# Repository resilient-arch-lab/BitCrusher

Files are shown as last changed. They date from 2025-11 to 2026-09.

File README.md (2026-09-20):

# BitCrusher: An Affordable, Open Source, Electromagnetic Fault Injection Platform
_NOTE: This repository is still under construction, and may be difficult to navigate in its current state_

Security researchers need attainable, effective tooling to secure computing infrastructure against physical attacks. Tools for hardware security research have been
getting cheaper and more effective over recent years, but EMFI tooling has been left behind. The cost of commercial EMFI tooling is typically on the order of tens to hundreds of thousands of dollars, and the highly-coupled proprietary equipment offers little insight to researchers developing or characterizing EMFI techniques. BitCrusher is being developed with the goal of addressing several challenges in this space:

- Supporting the continued improvement of open EMFI platform design techniques by contributing to the thread of research on the design of EMFI equipment
- Supporting the improvement of practical EMFI techniques and countermeasures through attainable and open domain specific instrumentation
- Lowering the high barrier to entry of replicating and expanding upon existing EMFI research by providing high performance equipment that is both affordable and easy to integrate with common existing hardware security instrumentation frameworks (e.g. ChipWhisperer)

## State of BitCrusher
BitCrusher was started as an undergraduate senior project in September 2025. Beginning April 2026, development efforts have been focused on working out design flaws and thoroughly verifying device performance. 

## Licensing
Following the licensing guidelines of [OSHWA](https://oshwa.org/), the components of BitCrusher fall under a combination of OSI-approved licenses. The following licenses were selected with the goals of maximizing this work's benefit to the open hardware and open security research communities and ensuring potential commercial utilization of this work similarly benefits those communities.  

**Firmware and Software:** BitCrusher firmware and software fall under the [GNU Affero General Public License v3.0](https://www.gnu.org/licenses/agpl-3.0.html) (AGPL-3.0). This includes the BitCrusher device firmware (`/firmware`) and the host-side python interface (`/interface`).  

**Hardware design:** The design materials of BitCrusher (including but not limited to materials in `/design`, excluding those covered under the firmware / software licensing scheme) are licensed under the [CERN Open Hardware Licence Version 2 – Strongly Reciprocal](https://gitlab.com/ohwr/project/cernohl/-/wikis/uploads/819d71bea3458f71fba6cf4fb0f2de6b/cern_ohl_s_v2.txt) (CERN-OHL-S-2.0). 

**Documentation:** Current BitCrusher documentation, including but not limited to user guides / instructions, written documentation of the design, and written engineering work / documentation is under the [Creative Commons Attribution-ShareAlike 4.0 International](https://creativecommons.org/licenses/by-sa/4.0/) license (CC BY-SA 4.0). In cases where documentation is accompanied by code, such as simulations and calculations in `/design-resources`, the code falls under the AGPL-3.0 license while the written work falls under the CC BY-SA 4.0 license. 

While there is currently no sound structure for project governance, the policy for potential future contributions to the project's documentation is that the contributions should be CC BY-SA 4.0 licensed under the title "BitCrusher" and attributed to the respective contributor(s).  

**Branding:** Since this work was named after the [digital audio effect](https://en.wikipedia.org/wiki/Bitcrusher), as well as the fact that this project is a non-commercial endeavor, no restrictions apply to the use of the name BitCrusher.

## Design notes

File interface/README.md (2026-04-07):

# Installation
1. initialize submodules
2. install libftd2xx on OS (e.g. from AUR)
3. run `configure-ft230x.sh` with the device connected
4. build `src/stm32flash` with `make`

*TODO: Finish this*

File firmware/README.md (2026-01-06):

# BitChrusher Firmware
## High Voltage Generation Control

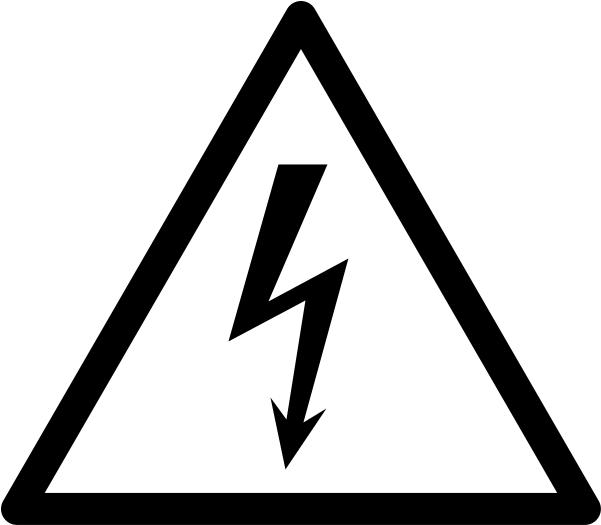
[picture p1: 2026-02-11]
design/graphics/high-voltage.jpg

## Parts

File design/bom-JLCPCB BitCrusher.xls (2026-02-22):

JLCPCB BOM Tool - BOM Matching
BOM name：bom-JLCPCB Assembly Order.xlsx |  |  | Download Time：2026-02-12 00:46:41 |  |  |  | * Our matching results are updated in real-time, but stock and prices may change. If it's been over 24 hours, please re-match before placing your order.
PCB Assembled Qty：5 |  |  | Est. Total Price：179.6794
Your BOM |  |  |  |  | Matched Parts |  |  |  |  |  |  | Order Information
Top Designator | Bottom Designator | Comment | Footprint | JLCPCB Part # | Matches | Part # | Manufacturer | Footprint | Description | Category | Warning | JLCPCB Part # | Product link | Lib Type | Qty | Source | Total Price ($)
C1,C11,C20,C21 |  | 4.7u | 0402 |  | Select by Customer | GRM155R61E475ME15D | Murata Electronics | 0402 | 25V 4.7uF X5R ±20% 0402 Multilayer Ceramic Capacitors MLCC - SMD/SMT ROHS | Multilayer Ceramic Capacitors MLCC - SMD/SMT | 1.The comment (GRM155R61E475ME15D) of this part does not match the one (4.7u) provided in your BOM. Please confirm; | C2858031 | https://jlcpcb.com/partdetail/3058877-GRM155R61E475ME15D/C2858031 | Extended | 24 | 24 JLCPCB | 0.9672
C6 |  | 10n | 0402 |  | Select by Customer | 0402B103K500NT | FH (Guangdong Fenghua Advanced Tech) | 0402 | 10nF 50V X7R ±10% 0402 Multilayer Ceramic Capacitors MLCC - SMD/SMT ROHS | Multilayer Ceramic Capacitors MLCC - SMD/SMT | 1.The comment (0402B103K500NT) of this part does not match the one (10n) provided in your BOM. Please confirm; | C1524 | https://jlcpcb.com/partdetail/1876-0402B103K500NT/C1524 | Extended | 20 | 20 JLCPCB | 0.022
C10,C12,C2,C3,C4,C5,C8,C9,CBOOT1,CBOOT2,CFF1,CFF2,COUT1,COUT5 |  | 100n | 0402 |  | Select by Customer | 0402B104K250NT | FH (Guangdong Fenghua Advanced Tech) | 0402 | 100nF 25V X7R ±10% 0402 Multilayer Ceramic Capacitors MLCC - SMD/SMT ROHS | Multilayer Ceramic Capacitors MLCC - SMD/SMT | 1.The comment (0402B104K250NT) of this part does not match the one (100n) provided in your BOM. Please confirm; 2.Multiple lines in the BOM have been matched to the same part. Please check if the matching is correct. ; 3.There may be multiple types of parts, but one type of part has been matched. Please check.; | C56392 | https://jlcpcb.com/partdetail/57421-0402B104K250NT/C56392 | Extended | 97 | 97 JLCPCB | 0.1358
C22,C23,C25 |  | 0.1u | 0402 |  | Select by Customer | 0402B104K250NT | FH (Guangdong Fenghua Advanced Tech) | 0402 | 100nF 25V X7R ±10% 0402 Multilayer Ceramic Capacitors MLCC - SMD/SMT ROHS | Multilayer Ceramic Capacitors MLCC - SMD/SMT | 1.The comment (0402B104K250NT) of this part does not match the one (0.1u) provided in your BOM. Please confirm; 2.Multiple lines in the BOM have been matched to the same part. Please check if the matching is correct. ; | C56392 | https://jlcpcb.com/partdetail/57421-0402B104K250NT/C56392 | Extended | 97 | 97 JLCPCB | 0.1358
C13,C14,C15,C16,C26,C7 |  | 1u | 0402 |  | Unconfirmed | CL05A105KA5NQNC | Samsung Electro-Mechanics | 0402 | 1uF 25V X5R ±10% 0402 Multilayer Ceramic Capacitors MLCC - SMD/SMT ROHS | Multilayer Ceramic Capacitors MLCC - SMD/SMT | 1.The comment (CL05A105KA5NQNC) of this part does not match the one (1u) provided in your BOM. Please confirm; | C52923 | https://jlcpcb.com/partdetail/53938-CL05A105KA5NQNC/C52923 | Basic | 40 | 40 JLCPCB | 0.132
C17,C18,CIN1,CIN2,CIN3,CIN4 |  | 4.7u | 1206 |  | Unconfirmed | 1206B475K500NT | FH (Guangdong Fenghua Advanced Tech) | 1206 | 4.7uF 50V X7R ±10% 1206 Multilayer Ceramic Capacitors MLCC - SMD/SMT ROHS | Multilayer Ceramic Capacitors MLCC - SMD/SMT | 1.The comment (1206B475K500NT) of this part does not match the one (4.7u) provided in your BOM. Please confirm; 2.There may be multiple types of parts, but one type of part has been matched. Please check.; | C29823 | https://jlcpcb.com/partdetail/30577-1206B475K500NT/C29823 | Basic | 38 | 38 JLCPCB | 1.4364
C19 |  | 240n | 0402 |  | Select by Customer | CL05B224KO5NNNC | Samsung Electro-Mechanics | 0402 | 16V 220nF X7R ±10% 0402 Multilayer Ceramic Capacitors MLCC - SMD/SMT ROHS | Multilayer Ceramic Capacitors MLCC - SMD/SMT |  | C16772 | https://jlcpcb.com/partdetail/17456-CL05B224KO5NNNC/C16772 | Basic | 20 | 20 JLCPCB | 0.082
C24,C27 |  | 1n | 0402 |  | Unconfirmed | 0402B102K500NT | FH (Guangdong Fenghua Advanced Tech) | 0402 | 1nF 50V X7R ±10% 0402 Multilayer Ceramic Capacitors MLCC - SMD/SMT ROHS | Multilayer Ceramic Capacitors MLCC - SMD/SMT | 1.The comment (0402B102K500NT) of this part does not match the one (1n) provided in your BOM. Please confirm; | C1523 | https://jlcpcb.com/partdetail/1875-0402B102K500NT/C1523 | Basic | 20 | 20 JLCPCB | 0.024
C28 |  | 68n | 0402 |  | Unconfirmed | CC0402KRX7R7BB683 | YAGEO | 0402 | 16V 68nF X7R ±10% 0402 Multilayer Ceramic Capacitors MLCC - SMD/SMT ROHS | Multilayer Ceramic Capacitors MLCC - SMD/SMT | 1.The comment (CC0402KRX7R7BB683) of this part does not match the one (68n) provided in your BOM. Please confirm; | C327019 | https://jlcpcb.com/partdetail/YAGEO-CC0402KRX7R7BB683/C327019 | Extended | 20 | 20 JLCPCB | 0.05
C29,C31 |  | 0.1n | 0402 |  | Unconfirmed | 0402CG101J500NT | FH (Guangdong Fenghua Advanced Tech) | 0402 | 100pF 50V C0G ±5% 0402 Multilayer Ceramic Capacitors MLCC - SMD/SMT ROHS | Multilayer Ceramic Capacitors MLCC - SMD/SMT | 1.The comment (0402CG101J500NT) of this part does not match the one (0.1n) provided in your BOM. Please confirm; 2.Multiple lines in the BOM have been matched to the same part. Please check if the matching is correct. ; | C1546 | https://jlcpcb.com/partdetail/1898-0402CG101J500NT/C1546 | Basic | 25 | 25 JLCPCB | 0.0275
C_CSF1 |  | 100p | 0402 |  | Unconfirmed | 0402CG101J500NT | FH (Guangdong Fenghua Advanced Tech) | 0402 | 100pF 50V C0G ±5% 0402 Multilayer Ceramic Capacitors MLCC - SMD/SMT ROHS | Multilayer Ceramic Capacitors MLCC - SMD/SMT | 1.The comment (0402CG101J500NT) of this part does not match the one (100p) provided in your BOM. Please confirm; 2.Multiple lines in the BOM have been matched to the same part. Please check if the matching is correct. ; | C1546 | https://jlcpcb.com/partdetail/1898-0402CG101J500NT/C1546 | Basic | 25 | 25 JLCPCB | 0.0275
C30 |  | 22u | 0603 |  | Unconfirmed
C32,C33,C34 |  | 10p | 0402 |  | Unconfirmed | CL05C100JB5NNNC | Samsung Electro-Mechanics | 0402 | 10pF 50V C0G ±5% 0402 Multilayer Ceramic Capacitors MLCC - SMD/SMT ROHS | Multilayer Ceramic Capacitors MLCC - SMD/SMT | 1.The comment (CL05C100JB5NNNC) of this part does not match the one (10p) provided in your BOM. Please confirm; | C32949 | https://jlcpcb.com/partdetail/33914-CL05C100JB5NNNC/C32949 | Basic | 25 | 25 JLCPCB | 0.1125
CBANK1,CBANK2,CBANK3,CBANK4,CBANK5 |  | FS55X105K631EHG | 2220 |  | Select by System | FS55X105K631EHG | PSA(Prosperity Dielectrics) | 2220 | 1uF 630V X7R ±10% 2220 Multilayer Ceramic Capacitors MLCC - SMD/SMT ROHS | Multilayer Ceramic Capacitors MLCC - SMD/SMT |  | C784102 | https://jlcpcb.com/partdetail/839502-FS55X105K631EHG/C784102 | Extended | 25 | 25 JLCPCB | 10.265
CHF1,CHF2 |  | 220n | 0805 |  | Unconfirmed | CL21B224KBFNNNE | Samsung Electro-Mechanics | 0805 | 220nF 50V X7R ±10% 0805 Multilayer Ceramic Capacitors MLCC - SMD/SMT ROHS | Multilayer Ceramic Capacitors MLCC - SMD/SMT | 1.The comment (CL21B224KBFNNNE) of this part does not match the one (220n) provided in your BOM. Please confirm; | C5378 | https://jlcpcb.com/partdetail/5810-CL21B224KBFNNNE/C5378 | Basic | 20 | 20 JLCPCB | 0.232
COUT2,COUT3,COUT4,COUT6,COUT7,COUT8 |  | 22u | 1210 |  | Select by Customer | GRM32ER71E226KE15L | Murata Electronics | 1210 | 22uF 25V X7R ±10% 1210 Multilayer Ceramic Capacitors MLCC - SMD/SMT ROHS | Multilayer Ceramic Capacitors MLCC - SMD/SMT | 1.The comment (GRM32ER71E226KE15L) of this part does not match the one (22u) provided in your BOM. Please confirm; | C21397 | https://jlcpcb.com/partdetail/MurataElectronics-GRM32ER71E226KE15L/C21397 | Extended | 30 | 30 JLCPCB | 6.807
D1,D2 |  | SP3031-01ETG | D_SOD-882 |  | Select by System | SP3031-01ETG | Littelfuse | SOD-882 | 0.8pF 1 1uA 5A@8/20us 5V 6V 7.5V IEC 61000-4-2、IEC 61000-4-5、IEC 61000-4-4 TVS Unidirectional SOD-882 ESD and Surge Protection (TVS/ESD) ROHS | ESD And Surge Protection (TVS/ESD) |  | C207283 | https://jlcpcb.com/partdetail/Littelfuse-SP303101ETG/C207283 | Extended | 12 | 12 JLCPCB | 1.9272
D3,D6 |  | 1N5822 | D_DO-201AD_P12.70mm_Horizontal |  | Select by System | 1N5822 | MDD(Microdiode Semiconductor) | DO-201AD | -65℃~+125℃ 1 Independent 3A 40V 500uA@40V 525mV@3A 80A DO-201AD Schottky Diodes ROHS | Schottky Diodes |  | C2476 | https://jlcpcb.com/partdetail/MDD_Microdiode_Semiconductor-1N5822/C2476 | Extended | 11 | 11 JLCPCB | 1.2331
D4 |  | D | D_SMA |  | Select by Customer | US2M | MDD(Microdiode Semiconductor) | SMA | -55℃~+150℃ 1.7V@2A 1kV 2A 50A 5uA@1kV 75ns Independent SMA Fast Recovery / High Efficiency Diodes ROHS | Fast Recovery / High Efficiency Diodes |  | C64958 | https://jlcpcb.com/partdetail/MDD_Microdiode_Semiconductor-US2M/C64958 | Extended | 13 | 13 JLCPCB | 0.286
D5 |  | 1N5819 | D_SOD-323 |  | Unconfirmed | 1N5819WS | Guangdong Hottech | SOD-323 | 1 Independent 1A 25A 40V 500uA@40V 600mV@1A SOD-323 Schottky Diodes ROHS | Schottky Diodes | 1.The comment (1N5819WS) of this part does not match the one (1N5819) provided in your BOM. Please confirm; | C191023 | https://jlcpcb.com/partdetail/GuangdongHottech-1N5819WS/C191023 | Basic | 20 | 20 JLCPCB | 0.174
D7 |  | D_Schottky | D_SOD-123 |  | Select by Customer | B5819W SL | Jiangsu Changjing Electronics Technology Co., Ltd. | SOD-123 | 1A 40V 600mV@1A 9A Independent SOD-123 Schottky Diodes ROHS | Schottky Diodes |  | C8598 | https://jlcpcb.com/partdetail/9093-B5819WSL/C8598 | Basic | 20 | 20 JLCPCB | 0.48
D8,D9 |  | HF1600G | D_DO-41_SOD81_P7.62mm_Horizontal |  | Select by System | HF1600G | LRC | DO-41 | -50℃~+150℃@(Tj) 1.2kV 1A 3.4V@0.5A 5uA@1200V 75ns Independent DO-41 Switching Diodes ROHS | Switching Diodes |  | C411154 | https://jlcpcb.com/partdetail/LRC-HF1600G/C411154 | Extended | 12 | 12 JLCPCB | 1.3932
J1 |  | BNC | KHBNC503511 |  | Select by Customer | KH-BNC50-3511 | Shenzhen Kinghelm Elec | 插件 | -55℃~+155℃ 1 3GHz 50Ω 9.5mm BNC Board Side Elbow Inner Bore Plugin Coaxial Connectors (RF) ROHS | Coaxial Connectors (RF) |  | C2837587 | https://jlcpcb.com/partdetail/Shenzhen_KinghelmElec-KH_BNC503511/C2837587 | Extended | 5 | 5 JLCPCB | 4.05
J2 |  | BWSMA-KWE-Z001 | SMA_BAT_Wireless_BWSMA-KWE-Z001 |  | Select by System | BWSMA-KWE-Z001 | BAT WIRELESS | 插件 | 1 5.3mm 50Ω Board Side Elbow Inner Bore SMA Plugin Coaxial Connectors (RF) ROHS | Coaxial Connectors (RF) |  | C496551 | https://jlcpcb.com/partdetail/BATWIRELESS-BWSMA_KWEZ001/C496551 | Extended | 5 | 5 JLCPCB | 2.479
J3,J4 |  | BWSMA-KE-Z001 | SMA_BAT_Wireless_BWSMA-KE-Z001 |  | Select by System | BWSMA-KE-Z001 | BAT WIRELESS | 插件 | -65℃~+165℃ 1 50Ω Board Side Inner Bore Positive Pin SMA Plugin Coaxial Connectors (RF) ROHS | Coaxial Connectors (RF) |  | C496549 | https://jlcpcb.com/partdetail/BATWIRELESS-BWSMA_KEZ001/C496549 | Extended | 10 | 10 JLCPCB | 3.127
J5 |  | SHOUHANTYPE-C14PCC-2.6 | TYPE-C-TH_TYPE-C-14P-CC-2.6 |  | Select by System | TYPE-C 14P CC-2.6 | SHOU HAN | 插件 | -30℃~+85℃ 1 10,000 Cycles 14P 20V 3A Black Female Type-C Vertical, Flag 插件 USB Connectors ROHS | USB Connectors |  | C5187475 | https://jlcpcb.com/partdetail/SHOUHAN-TYPE_C_14P_CC_26/C5187475 | Extended | 5 | 5 JLCPCB | 2.9845
J6,J7 |  | Conn_01x04_Pin | PinHeader_1x04_P2.54mm_Vertical |  | Select by Customer | 2.54-1*40P直针 | BOOMELE(Boom Precision Elec) | 插件,P=2.54mm | -25℃~+85℃ 1 1x40P 2.54mm 2.5mm 3A 3mm 40P 6mm Black Brass Gold Pin Header Through Hole Plugin,P=2.54mm Pin Headers ROHS | Pin Headers | 1.Multiple lines in the BOM have been matched to the same part. Please check if the matching is correct. ; | C2337 | https://jlcpcb.com/partdetail/2712-2_54_1_40P/C2337 | Extended | 20 | 20 JLCPCB | 2.73
J8,J9 |  | Conn_01x03_Pin | PinHeader_1x03_P2.54mm_Vertical |  | Select by Customer | 2.54-1*40P直针 | BOOMELE(Boom Precision Elec) | 插件,P=2.54mm | -25℃~+85℃ 1 1x40P 2.54mm 2.5mm 3A 3mm 40P 6mm Black Brass Gold Pin Header Through Hole Plugin,P=2.54mm Pin Headers ROHS | Pin Headers | 1.Multiple lines in the BOM have been matched to the same part. Please check if the matching is correct. ; | C2337 | https://jlcpcb.com/partdetail/2712-2_54_1_40P/C2337 | Extended | 20 | 20 JLCPCB | 2.73
L1 |  | 15.4u | L_TechFuse_SL0630 |  | Select by Customer | SL0630-150M | TECHFUSE | SMD,7.1x6.6mm | 115mΩ 15uH 3.5A 4.5A ±20% SMD,7.1x6.6mm Inductors (SMD) ROHS | Inductors (SMD) |  | C22463824 | https://jlcpcb.com/partdetail/TECHFUSE-SL0630150M/C22463824 | Extended | 5 | 5 JLCPCB | 0.424
L2 |  | 12.1u | L_TechFuse_SL0630 |  | Select by Customer | SL0630-100M | TECHFUSE | SMD,7.1x6.6mm | 10uH 5.5A 5A 99.5mΩ ±20% SMD,7.1x6.6mm Inductors (SMD) ROHS | Inductors (SMD) |  | C22463823 | https://jlcpcb.com/partdetail/TECHFUSE-SL0630100M/C22463823 | Extended | 5 | 5 JLCPCB | 0.394
Q1 |  | Q_NMOS_DGS | TO-252-2 |  | Select by Customer | SW4N60 | Samwin | TO-252-2 | -55℃~+150℃ 1 N-channel 147W 17nC 2.2Ω@10V 4.5V 4A 586pF 600V 7.6pF 71pF N-Channel TO-252-2 MOSFETs ROHS | MOSFETs |  | C381523 | https://jlcpcb.com/partdetail/Samwin-SW4N60/C381523 | Extended | 5 | 5 JLCPCB | 1.26
Q2 |  | 2SA1213 | SOT-89-3 |  | Select by System | 2SA1213 | hongjiacheng | SOT-89 | -55℃~+150℃ 1 PNP 100nA 120MHz 2A 500mV 500mW 50V 5V 70 PNP SOT-89 Bipolar (BJT) ROHS | Bipolar (BJT) |  | C20069144 | https://jlcpcb.com/partdetail/hongjiacheng-2SA1213/C20069144 | Extended | 7 | 7 JLCPCB | 0.4424
R1,R5 |  | 10k | 0402 |  | Unconfirmed | 0402WGF1002TCE | UNI-ROYAL(Uniroyal Elec) | 0402 | -55℃~+155℃ 10kΩ 50V 62.5mW Thick Film Resistor ±1% ±100ppm/℃ 0402 Chip Resistor - Surface Mount ROHS | Chip Resistor - Surface Mount | 1.The comment (0402WGF1002TCE) of this part does not match the one (10k) provided in your BOM. Please confirm; | C25744 | https://jlcpcb.com/partdetail/26487-0402WGF1002TCE/C25744 | Basic | 20 | 20 JLCPCB | 0.016
R2,R3 |  | 5.1k | 0603 |  | Unconfirmed | 0603WAF5101T5E | UNI-ROYAL(Uniroyal Elec) | 0603 | -55℃~+155℃ 100mW 5.1kΩ 75V Thick Film Resistor ±1% ±100ppm/℃ 0603 Chip Resistor - Surface Mount ROHS | Chip Resistor - Surface Mount | 1.The comment (0603WAF5101T5E) of this part does not match the one (5.1k) provided in your BOM. Please confirm; | C23186 | https://jlcpcb.com/partdetail/23913-0603WAF5101T5E/C23186 | Basic | 20 | 20 JLCPCB | 0.024
R4 |  | 4.7k | 0402 |  | Unconfirmed | 0402WGF4701TCE | UNI-ROYAL(Uniroyal Elec) | 0402 | -55℃~+155℃ 4.7kΩ 50V 62.5mW Thick Film Resistor ±1% ±100ppm/℃ 0402 Chip Resistor - Surface Mount ROHS | Chip Resistor - Surface Mount | 1.The comment (0402WGF4701TCE) of this part does not match the one (4.7k) provided in your BOM. Please confirm; | C25900 | https://jlcpcb.com/partdetail/26643-0402WGF4701TCE/C25900 | Basic | 20 | 20 JLCPCB | 0.016
R6 |  | 60k | 0603 |  | Select by Customer | 0603WAF6042T5E | UNI-ROYAL(Uniroyal Elec) | 0603 | -55℃~+155℃ 100mW 60.4kΩ 75V Thick Film Resistor ±1% ±100ppm/℃ 0603 Chip Resistor - Surface Mount ROHS | Chip Resistor - Surface Mount | 1.The comment (0603WAF6042T5E) of this part does not match the one (60k) provided in your BOM. Please confirm; | C23089 | https://jlcpcb.com/partdetail/23816-0603WAF6042T5E/C23089 | Extended | 20 | 20 JLCPCB | 0.024
R7 |  | 1.6 | 0603 |  | Unconfirmed | FRC0603F1R60TS | FOJAN | 0603 | -55℃~+155℃ 1.6Ω 100mW 75V Thick Film Resistor ±1% ±200ppm/℃ 0603 Chip Resistor - Surface Mount ROHS | Chip Resistor - Surface Mount | 1.The comment (FRC0603F1R60TS) of this part does not match the one (1.6) provided in your BOM. Please confirm; | C2930144 | https://jlcpcb.com/partdetail/FOJAN-FRC0603F1R60TS/C2930144 | Extended | 20 | 20 JLCPCB | 0.028
R10,R11,R12,R8,R9 |  | 2M | 0805 |  | Select by Customer | 0805W8F2004T5E | UNI-ROYAL(Uniroyal Elec) | 0805 | -55℃~+155℃ 125mW 150V 2MΩ Thick Film Resistor ±1% ±100ppm/℃ 0805 Chip Resistor - Surface Mount ROHS | Chip Resistor - Surface Mount | 1.The comment (0805W8F2004T5E) of this part does not match the one (2M) provided in your BOM. Please confirm; | C26112 | https://jlcpcb.com/partdetail/26855-0805W8F2004T5E/C26112 | Extended | 35 | 35 JLCPCB | 0.098
R13 |  | 1.5M,1000V,500mW |  |  | Unconfirmed
R14,R15,R16 |  | 1 | 0603 |  | Unconfirmed | 0603WAF100KT5E | UNI-ROYAL(Uniroyal Elec) | 0603 | -55℃~+155℃ 100mW 1Ω 75V Thick Film Resistor ±1% ±400ppm/℃ 0603 Chip Resistor - Surface Mount ROHS | Chip Resistor - Surface Mount | 1.The comment (0603WAF100KT5E) of this part does not match the one (1) provided in your BOM. Please confirm; | C22936 | https://jlcpcb.com/partdetail/23663-0603WAF100KT5E/C22936 | Basic | 25 | 25 JLCPCB | 0.05
R17 |  | 330 | 0603 |  | Unconfirmed | 0603WAF3300T5E | UNI-ROYAL(Uniroyal Elec) | 0603 | -55℃~+155℃ 100mW 330Ω 75V Thick Film Resistor ±1% ±100ppm/℃ 0603 Chip Resistor - Surface Mount ROHS | Chip Resistor - Surface Mount | 1.The comment (0603WAF3300T5E) of this part does not match the one (330) provided in your BOM. Please confirm; | C23138 | https://jlcpcb.com/partdetail/23865-0603WAF3300T5E/C23138 | Basic | 20 | 20 JLCPCB | 0.024
R18 |  | 10M | 0603 |  | Unconfirmed | 0603WAF1005T5E | UNI-ROYAL(Uniroyal Elec) | 0603 | -55℃~+155℃ 100mW 10MΩ 75V Thick Film Resistor ±1% ±100ppm/℃ 0603 Chip Resistor - Surface Mount ROHS | Chip Resistor - Surface Mount | 1.The comment (0603WAF1005T5E) of this part does not match the one (10M) provided in your BOM. Please confirm; | C7250 | https://jlcpcb.com/partdetail/7726-0603WAF1005T5E/C7250 | Basic | 20 | 20 JLCPCB | 0.036
R19,R23 |  | 4.3M | 0603 |  | Unconfirmed | FRC0603F4304TS | FOJAN | 0603 | -55℃~+155℃ 100mW 4.3MΩ 75V Thick Film Resistor ±1% ±100ppm/℃ 0603 Chip Resistor - Surface Mount ROHS | Chip Resistor - Surface Mount | 1.The comment (FRC0603F4304TS) of this part does not match the one (4.3M) provided in your BOM. Please confirm; | C2930152 | https://jlcpcb.com/partdetail/FOJAN-FRC0603F4304TS/C2930152 | Extended | 20 | 20 JLCPCB | 0.022
R20,R24 |  | 4.7M | 0603 |  | Unconfirmed | 0603WAF4704T5E | UNI-ROYAL(Uniroyal Elec) | 0603 | -55℃~+155℃ 100mW 4.7MΩ 75V Thick Film Resistor ±1% ±100ppm/℃ 0603 Chip Resistor - Surface Mount ROHS | Chip Resistor - Surface Mount | 1.The comment (0603WAF4704T5E) of this part does not match the one (4.7M) provided in your BOM. Please confirm; | C23163 | https://jlcpcb.com/partdetail/23890-0603WAF4704T5E/C23163 | Extended | 20 | 20 JLCPCB | 0.026
R21,R22 |  | 0R,200V,30A | 2512 |  | Select by Customer | 25121WJ0000T4E | UNI-ROYAL(Uniroyal Elec) | 2512 | -55℃~+155℃ 0Ω 1W 200V Thick Film Resistor ±5% ±800ppm/℃ 2512 Chip Resistor - Surface Mount ROHS | Chip Resistor - Surface Mount |  | C25469 | https://jlcpcb.com/partdetail/26212-25121WJ0000T4E/C25469 | Extended | 18 | 18 JLCPCB | 0.3906
R25 |  | 330 | 2512 |  | Unconfirmed | 3521330RFT | TE Connectivity | 2512 | -55℃~+155℃ 2W 330Ω Thick Film Resistor ±1% ±100ppm/℃ 2512 Chip Resistor - Surface Mount ROHS | Chip Resistor - Surface Mount | 1.The comment (3521330RFT) of this part does not match the one (330) provided in your BOM. Please confirm; | C4134246 | https://jlcpcb.com/partdetail/TEConnectivity-3521330RFT/C4134246 | Extended | 5 | 5 JLCPCB | 1.5555
R26 |  | 0 | 0603 |  | Unconfirmed | 0603WAF0000T5E | UNI-ROYAL(Uniroyal Elec) | 0603 | -55℃~+155℃ 0Ω 100mW 75V Thick Film Resistor ±1% 0603 Chip Resistor - Surface Mount ROHS | Chip Resistor - Surface Mount | 1.The comment (0603WAF0000T5E) of this part does not match the one (0) provided in your BOM. Please confirm; | C21189 | https://jlcpcb.com/partdetail/21903-0603WAF0000T5E/C21189 | Basic | 20 | 20 JLCPCB | 0.024
RCS1 |  | 500m,3W | 2512 |  | Select by Customer | HoJLR2512-3W-500mR-1% | Milliohm | 2512 | 3W 500mΩ Current Sense Resistor SMD ±1% 2512 Current Sense Resistors / Shunt Resistors ROHS | Current Sense Resistors / Shunt Resistors |  | C2904268 | https://jlcpcb.com/partdetail/Milliohm-HoJLR2512_3W_500mR_1/C2904268 | Extended | 7 | 7 JLCPCB | 0.4921
RFBB1 |  | 4.76K | 0603 |  | Select by Customer | 0603WAF4871T5E | UNI-ROYAL(Uniroyal Elec) | 0603 | -55℃~+155℃ 100mW 4.87kΩ 75V Thick Film Resistor ±1% ±100ppm/℃ 0603 Chip Resistor - Surface Mount ROHS | Chip Resistor - Surface Mount |  | C23045 | https://jlcpcb.com/partdetail/23772-0603WAF4871T5E/C23045 | Extended | 20 | 20 JLCPCB | 0.026
RFBB2 |  | 20k | 0603 |  | Select by System | 0603WAF2002T5E | UNI-ROYAL(Uniroyal Elec) | 0603 | -55℃~+155℃ 100mW 20kΩ 75V Thick Film Resistor ±1% ±100ppm/℃ 0603 Chip Resistor - Surface Mount ROHS | Chip Resistor - Surface Mount |  | C4184 | https://jlcpcb.com/partdetail/4591-0603WAF2002T5E/C4184 | Basic | 20 | 20 JLCPCB | 0.024
RFBT1,RFBT2,RPG1,RPG2 |  | 100k | 0603 |  | Unconfirmed | 0603WAF1003T5E | UNI-ROYAL(Uniroyal Elec) | 0603 | -55℃~+155℃ 100kΩ 100mW 75V Thick Film Resistor ±1% ±100ppm/℃ 0603 Chip Resistor - Surface Mount ROHS | Chip Resistor - Surface Mount | 1.There may be multiple types of parts, but one type of part has been matched. Please check.; | C25803 | https://jlcpcb.com/partdetail/26546-0603WAF1003T5E/C25803 | Basic | 30 | 30 JLCPCB | 0.033
RP_B1 |  | WSHP2818R0200FEA | WSHP2818R0200FEA |  | Select by System | WSHP2818R0200FEA | Vishay Intertech | 2818 | 10W 20mΩ Current Sense Resistor SMD ±1% ±75ppm/℃ 2818 Current Sense Resistors / Shunt Resistors ROHS | Current Sense Resistors / Shunt Resistors |  | C2090752 | https://jlcpcb.com/partdetail/VishayIntertech-WSHP2818R0200FEA/C2090752 | Extended | 5 | 5 JLCPCB | 5.771
R_ADJ1 |  | 20k | 0402 |  | Select by Customer | 0402WGJ0203TCE | UNI-ROYAL(Uniroyal Elec) | 0402 | -55℃~+155℃ 20kΩ 50V 62.5mW Thick Film Resistor ±100ppm/℃ ±5% 0402 Chip Resistor - Surface Mount ROHS | Chip Resistor - Surface Mount |  | C25545 | https://jlcpcb.com/partdetail/26288-0402WGJ0203TCE/C25545 | Extended | 20 | 20 JLCPCB | 0.012
R_ADJ2 |  | 40k | 0402 |  | Select by Customer | GR0402J40KTAG00 | GiantOhm | 0402 | -55℃~+155℃ 40kΩ 50V 62.5mW Thick Film Resistor ±100ppm/℃ ±5% 0402 Chip Resistor - Surface Mount ROHS |  |  | C49654409 | https://jlcpcb.com/partdetail/GiantOhm-GR0402J40KTAG00/C49654409 | Extended | 20 | 20 JLCPCB | 0.008
R_CSF1 |  | 3.8k | 0402 |  | Select by Customer | 0402WGF3901TCE | UNI-ROYAL(Uniroyal Elec) | 0402 | -55℃~+155℃ 3.9kΩ 50V 62.5mW Thick Film Resistor ±1% ±100ppm/℃ 0402 Chip Resistor - Surface Mount ROHS | Chip Resistor - Surface Mount |  | C51721 | https://jlcpcb.com/partdetail/52734-0402WGF3901TCE/C51721 | Extended | 20 | 20 JLCPCB | 0.014
U1 |  | STM32F303RETx | LQFP-64_10x10mm_P0.5mm |  | Select by Customer | STM32F303RET6 | STMicroelectronics | LQFP-64(10x10) | -40℃~+85℃ 12bit 12bit 2V~3.6V 32 Bit 51 512KB 72MHz 80KB ARM Cortex-M4 Built-in FLASH LQFP-64(10x10) Microcontrollers (MCU/MPU/SOC) ROHS | Microcontrollers (MCU/MPU/SOC) |  | C183214 | https://jlcpcb.com/partdetail/STMicroelectronics-STM32F303RET6/C183214 | Extended | 5 | 5 JLCPCB | 24.504
U2 |  | USBLC6-2SC6 | SOT-23-6 |  | Select by System | USBLC6-2SC6 | TECH PUBLIC | SOT-23-6 | -55℃~+125℃ 0.35pF 12V 150W 2 5V 6A 6V 80nA ESD IEC 61000-4-2、IEC 61000-4-5、IEC 61000-4-4 Unidirectional SOT-23-6 ESD and Surge Protection (TVS/ESD) ROHS | ESD And Surge Protection (TVS/ESD) |  | C2827654 | https://jlcpcb.com/partdetail/TECHPUBLIC-USBLC62SC6/C2827654 | Extended | 9 | 9 JLCPCB | 0.3582
U3 |  | FT230XQ | QFN-16-1EP_4x4mm_P0.65mm_EP2.1x2.1mm |  | Unconfirmed | FT230XQ-R | FTDI | QFN-16-EP(4x4) | -40℃~+85℃ 125uA 3.3V~5V 8mA USB 2.0 USB to UART QFN-16-EP(4x4) USB Converters ROHS | USB Converters | 1.The comment (FT230XQ-R) of this part does not match the one (FT230XQ) provided in your BOM. Please confirm; | C128629 | https://jlcpcb.com/partdetail/FTDI-FT230XQR/C128629 | Extended | 5 | 5 JLCPCB | 51.8105
U4 |  | TPS7A2050PDQN | Texas_X2SON-4_1x1mm_P0.65mm |  | Unconfirmed | TPS7A2050PDQNR | Texas Instruments | X2-SON-4-EP(1x1) | -40℃~+125℃@(Tj) 1 10uVrms 140mV@(300mA) 300mA 5V 6.5uA 60dB@(100kHz) 6V Fixed Positive Soft Start、Enable X2-SON-4-EP(1x1) Voltage Regulators - Linear, Low Drop Out (LDO) Regulators ROHS | Voltage Regulators - Linear, Low Drop Out (LDO) Regulators | 1.The comment (TPS7A2050PDQNR) of this part does not match the one (TPS7A2050PDQN) provided in your BOM. Please confirm; | C2866499 | https://jlcpcb.com/partdetail/TexasInstruments-TPS7A2050PDQNR/C2866499 | Extended | 7 | 7 JLCPCB | 1.8557
U5 |  | TPS7A2033PDQN | Texas_X2SON-4_1x1mm_P0.65mm |  | Unconfirmed | TPS7A2033PDQNR | Texas Instruments | SON-4(1x1) | -40℃~+125℃@(Tj) 1 10uVrms 140mV@(300mA) 15uA 3.3V 300mA 6V 92dB@(1kHz) Fixed Over Current Protection、Over Temperature Protection、Soft Start、Enable Positive SON-4(1x1) Voltage Regulators - Linear, Low Drop Out (LDO) Regulators ROHS | Voltage Regulators - Linear, Low Drop Out (LDO) Regulators | 1.The comment (TPS7A2033PDQNR) of this part does not match the one (TPS7A2033PDQN) provided in your BOM. Please confirm; | C2871641 | https://jlcpcb.com/partdetail/TexasInstruments-TPS7A2033PDQNR/C2871641 | Extended | 5 | 5 JLCPCB | 1.189
U6,U7 |  | LMR33630ADDA | Texas_HSOP-8-1EP_3.9x4.9mm_P1.27mm_ThermalVias |  | Select by System | LMR33630ADDA | Texas Instruments | ESOP-8 | -40℃~+125℃@(TJ) 1 1V~24V 24uA 3.8V~36V 3A 400kHz Adjustable Buck Buck Built-in Yes ESOP-8 DC-DC Converters ROHS | DC-DC Converters |  | C2866787 | https://jlcpcb.com/partdetail/TexasInstruments-LMR33630ADDA/C2866787 | Extended | 10 | 10 JLCPCB | 6.569
U8 |  | TLP152TPL_E | TLP152_4P55X3P7_TOS |  | Select by System | TLP152(TPL,E | TOSHIBA | SOIC-5-4.6mm | -40℃~+100℃ 1 1.57V 10V~30V 15mA 170ns 190ns 20kV/us 260mW 2A 3.75kV 5V 7.5mA DC SOIC-5-4.6mm Logic Output Optoisolators ROHS | Logic Output Optoisolators |  | C150122 | https://jlcpcb.com/partdetail/TOSHIBA-TLP152_TPLE/C150122 | Extended | 5 | 5 JLCPCB | 2.2105
J10 |  | PJ-002BH | PJ-002B_CUI |  | Select by System | PJ-002BH | CUI | 插件 | Plugin DC Power Connectors ROHS | DC Power Connectors |  | C22359705 | https://jlcpcb.com/partdetail/CUI-PJ002BH/C22359705 | Extended | 5 | 3 JLCPCB | 3.4293
Q3 |  | GAN080-650EBE | GAN080650EBEZ |  | Unconfirmed | GAN080-650EBEZ | Nexperia | DFN8080-8 | -55℃~+150℃ 0.5pF 1 N-channel 2.5V@30.7mA 225pF 240W 29A 6.2nC@6V 650V 70pF 80mΩ@6V DFN8080-8 GaN Transistors(GaN HEMT) ROHS | MOSFETs | 1.The comment (GAN080-650EBEZ) of this part does not match the one (GAN080-650EBE) provided in your BOM. Please confirm; | C20235155 | https://jlcpcb.com/partdetail/Nexperia-GAN080650EBEZ/C20235155 | Extended | 5 | 1 JLCPCB | 18.6085
RP_LIM1 |  | PF2472-0R1F1 | TO-247-2_Horizontal_TabDown |  | Select by System | PF2472-0R1F1 | Riedon | TO-247-2 | -55℃~+155℃ 100W 100mΩ Thin Film Resistor ±1% ±100ppm/℃ TO-247-2 Through Hole Resistors ROHS | Through Hole Resistors |  | C3387781 | https://jlcpcb.com/partdetail/Riedon-PF24720R1F1/C3387781 | Extended | 5 | 0 JLCPCB | 0
T1 |  | DA2033-AL | SOP254P2413X978-12N |  | Unconfirmed | DA2033-ALD | Coilcraft | SMD-12 | SMD-12 New Arrivals ROHS |  | 1.The comment (DA2033-ALD) of this part does not match the one (DA2033-AL) provided in your BOM. Please confirm; | C5142798 | https://jlcpcb.com/partdetail/Coilcraft-DA2033ALD/C5142798 | Extended | 5 | 0 JLCPCB | 0
U9 |  | MAX22702EASA+ | 21-0041-A_8L |  | Select by System | MAX22702EASA+ | Analog Devices Inc./Maxim Integrated | SOIC-8 | SOIC-8 Isolators - Gate Drivers ROHS | Isolators - Gate Drivers |  | C17268134 | https://jlcpcb.com/partdetail/18397266-MAX22702EASA/C17268134 | Extended | 5 | 2 JLCPCB | 13.8594

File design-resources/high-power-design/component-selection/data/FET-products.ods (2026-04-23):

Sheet: SiCFETs
Datasheet | Image | DK Part # | Mfr Part # | Mfr | Supplier | Description | Stock | Price | @ qty | Min Qty | Package | Series | Product Status | FET Type | Technology | Drain to Source Voltage (Vdss) | Current - Continuous Drain (Id) @ 25°C | Drive Voltage (Max Rds On, Min Rds On) | Rds On (Max) @ Id, Vgs | Vgs(th) (Max) @ Id | Gate Charge (Qg) (Max) @ Vgs | Vgs (Max) | Input Capacitance (Ciss) (Max) @ Vds | FET Feature | Power Dissipation (Max) | Operating Temperature | Grade | Qualification | Mounting Type | Supplier Device Package | Package / Case | URL
https://www.infineon.com/assets/row/public/documents/24/49/infineon-imbg65r040m2h-datasheet-en.pdf | //mm.digikey.com/Volume0/opasdata/d220001/medias/images/6167/448%7EPPG-TO263-7-12%7E%7E7.jpg | 448-IMBG65R040M2HXTMA1TR-ND,448-IMBG65R040M2HXTMA1CT-ND,448-IMBG65R040M2HXTMA1DKR-ND | IMBG65R040M2HXTMA1 | Infineon Technologies | Infineon Technologies | SILICON CARBIDE MOSFET | 1905 | 8.36 | 0 | 1 | Tape & Reel (TR),Cut Tape (CT),Digi-Reel® | CoolSiC™ Gen 2 | Active | N-Channel | SiCFET (Silicon Carbide) | 650 V | 49A (Tc) | 15V, 20V | 49mOhm @ 22.9A, 18V | 5.6V @ 4.6mA | 28 nC @ 18 V | +23V, -7V | 997 pF @ 400 V | - | 197W (Tc) | -55°C ~ 175°C (TJ) | - | - | Surface Mount | PG-TO263-7-12 | TO-263-8, D2PAK (7 Leads + Tab), TO-263CA | https://www.digikey.com/en/products/detail/infineon-technologies/IMBG65R040M2HXTMA1/22157745
https://assets.wolfspeed.com/uploads/2024/01/Wolfspeed_C3M0060065J_data_sheet.pdf | //mm.digikey.com/Volume0/opasdata/d220001/medias/images/6531/1697%7ETO263-7%7E%7E7.JPG | 1697-C3M0060065J-ND | C3M0060065J | Wolfspeed, Inc. | Wolfspeed, Inc. | SICFET N-CH 650V 36A TO263-7 | 2688 | 11.78 | 0 | 1 | Tube | C3M™ | Active | N-Channel | SiCFET (Silicon Carbide) | 650 V | 36A (Tc) | 15V | 79mOhm @ 13.2A, 15V | 3.6V @ 5mA | 46 nC @ 15 V | +15V, -4V | 1020 pF @ 600 V | - | 136W (Tc) | -40°C ~ 175°C (TJ) | - | - | Surface Mount | TO-263-7 | TO-263-8, D2PAK (7 Leads + Tab), TO-263CA | https://www.digikey.com/en/products/detail/wolfspeed-inc/C3M0060065J/12525328
//mm.digikey.com/Volume0/opasdata/d220001/medias/docus/6465/IMZA65R026M2HXKSA1.pdf | //mm.digikey.com/Volume0/opasdata/d220001/medias/images/6530/MFG_448%7EPPG-TO247-4-8%7E%7E4.jpg | 448-IMZA65R026M2HXKSA1-ND | IMZA65R026M2HXKSA1 | Infineon Technologies | Infineon Technologies | IMZA65R026M2HXKSA1 | 511 | 12.3 | 0 | 1 | Tube | CoolSiC™ | Active | N-Channel | SiCFET (Silicon Carbide) | 650 V | 64A (Tc) | 15V, 20V | 24mOhm @ 34.5A, 20V | 5.6V @ 7mA | 42 nC @ 18 V | +23V, -7V | 1499 pF @ 400 V | - | 227W (Tc) | -55°C ~ 175°C (TJ) | - | - | Through Hole | PG-TO247-4-8 | TO-247-4 | https://www.digikey.com/en/products/detail/infineon-technologies/IMZA65R026M2HXKSA1/25664319
https://www.infineon.com/assets/row/public/documents/24/49/infineon-imlt65r020m2h-datasheet-en.pdf | //mm.digikey.com/Volume0/opasdata/d220001/medias/images/6536/MFG_448%7EP-PG-HDSOP-16-6%7E%7E16.jpg | 448-IMLT65R020M2HXTMA1TR-ND,448-IMLT65R020M2HXTMA1CT-ND,448-IMLT65R020M2HXTMA1DKR-ND | IMLT65R020M2HXTMA1 | Infineon Technologies | Infineon Technologies | SICFET N-CH 650V 107A HDSOP-16 | 901 | 12.63 | 0 | 1 | Tape & Reel (TR),Cut Tape (CT),Digi-Reel® | CoolSiC™ Gen 2 | Active | N-Channel | SiCFET (Silicon Carbide) | 650 V | 107A (Tc) | 15V, 18V | 24mOhm @ 46.9A, 18V | 5.6V @ 9.5mA | 57 nC @ 18 V | +23V, -7V | 2038 pF @ 400 V | - | 454W (Tc) | -55°C ~ 175°C (TJ) | - | - | Surface Mount | PG-HDSOP-16-6 | 16-PowerSOP Module | https://www.digikey.com/en/products/detail/infineon-technologies/IMLT65R020M2HXTMA1/23018601
https://www.infineon.com/dgdl/Infineon-IMT65R020M2H-DataSheet-v02_01-EN.pdf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 | //mm.digikey.com/Volume0/opasdata/d220001/medias/images/6402/MFG_448%7EPPG-HSOF-8-2%7E%7E8.jpg | 448-IMT65R020M2HXUMA1TR-ND,448-IMT65R020M2HXUMA1CT-ND,448-IMT65R020M2HXUMA1DKR-ND | IMT65R020M2HXUMA1 | Infineon Technologies | Infineon Technologies | SILICON CARBIDE MOSFET | 1229 | 12.71 | 0 | 1 | Tape & Reel (TR),Cut Tape (CT),Digi-Reel® | CoolSiC™ | Active | N-Channel | SiCFET (Silicon Carbide) | 650 V | 105A (Tc) | 15V, 20V | 18mOhm @ 46.9A, 20V | 5.6V @ 9.5mA | 57 nC @ 18 V | +23V, -7V | 2038 pF @ 400 V | - | 440W (Tc) | -55°C ~ 175°C (TJ) | - | - | Surface Mount | PG-HSOF-8-2 | 8-PowerSFN | https://www.digikey.com/en/products/detail/infineon-technologies/IMT65R020M2HXUMA1/25902344
https://www.infineon.com/dgdl/Infineon-IMW65R027M1H-DataSheet-v02_00-EN.pdf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 | //mm.digikey.com/Volume0/opasdata/d220001/medias/images/6311/448%7EPPG-TO247-3-41%7E%7E3.jpg | 448-IMW65R027M1HXKSA1-ND | IMW65R027M1HXKSA1 | Infineon Technologies | Infineon Technologies | MOSFET 650V NCH SIC TRENCH | 1016 | 12.73 | 0 | 1 | Tube | CoolSIC™ M1 | Active | N-Channel | SiCFET (Silicon Carbide) | 650 V | 47A (Tc) | 18V | 34mOhm @ 38.3A, 18V | 5.7V @ 11mA | 62 nC @ 18 V | +23V, -5V | 2131 pF @ 400 V | - | 189W (Tc) | -55°C ~ 150°C (TJ) | - | - | Through Hole | PG-TO247-3-41 | TO-247-3 | https://www.digikey.com/en/products/detail/infineon-technologies/IMW65R027M1HXKSA1/11483554
https://assets.wolfspeed.com/uploads/2024/01/Wolfspeed_C3M0045065J1_data_sheet.pdf | //mm.digikey.com/Volume0/opasdata/d220001/medias/images/6531/1697%7ETO263-7%7E%7E7.JPG | 1697-C3M0045065J1-ND | C3M0045065J1 | Wolfspeed, Inc. | Wolfspeed, Inc. | 650V 45 M SIC MOSFET | 395 | 13.92 | 0 | 1 | Tube | C3M™ | Active | N-Channel | SiCFET (Silicon Carbide) | 650 V | 47A (Tc) | 15V | 60mOhm @ 17.6A, 15V | 3.6V @ 4.84mA | 61 nC @ 15 V | +19V, -8V | 1621 pF @ 400 V | - | 147W (Tc) | -40°C ~ 150°C (TJ) | - | - | Surface Mount | TO-263-7 | TO-263-8, D2PAK (7 Leads + Tab), TO-263CA | https://www.digikey.com/en/products/detail/wolfspeed-inc/C3M0045065J1/15814411
https://www.infineon.com/assets/row/public/documents/24/49/infineon-imlt65r015m2h-datasheet-en.pdf | //mm.digikey.com/Volume0/opasdata/d220001/medias/images/6536/MFG_448%7EP-PG-HDSOP-16-6%7E%7E16.jpg | 448-IMLT65R015M2HXTMA1TR-ND,448-IMLT65R015M2HXTMA1CT-ND,448-IMLT65R015M2HXTMA1DKR-ND | IMLT65R015M2HXTMA1 | Infineon Technologies | Infineon Technologies | SICFET N-CH 650V 142A HDSOP-16 | 774 | 15.17 | 0 | 1 | Tape & Reel (TR),Cut Tape (CT),Digi-Reel® | CoolSiC™ Gen 2 | Active | N-Channel | SiCFET (Silicon Carbide) | 650 V | 142A (Tc) | 15V, 18V | 18mOhm @ 64.2A, 18V | 5.6V @ 13mA | 79 nC @ 18 V | +23V, -7V | 2792 pF @ 400 V | - | 600W (Tc) | -55°C ~ 175°C (TJ) | - | - | Surface Mount | PG-HDSOP-16-6 | 16-PowerSOP Module | https://www.digikey.com/en/products/detail/infineon-technologies/IMLT65R015M2HXTMA1/23018586
https://www.infineon.com/dgdl/Infineon-IMT65R015M2H-DataSheet-v02_01-EN.pdf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 | //mm.digikey.com/Volume0/opasdata/d220001/medias/images/6402/MFG_448%7EPPG-HSOF-8-2%7E%7E8.jpg | 448-IMT65R015M2HXUMA1TR-ND,448-IMT65R015M2HXUMA1CT-ND,448-IMT65R015M2HXUMA1DKR-ND | IMT65R015M2HXUMA1 | Infineon Technologies | Infineon Technologies | SILICON CARBIDE MOSFET | 1020 | 15.24 | 0 | 1 | Tape & Reel (TR),Cut Tape (CT),Digi-Reel® | CoolSiC™ | Active | N-Channel | SiCFET (Silicon Carbide) | 650 V | 131A (Tc) | 15V, 20V | 13.2mOhm @ 64.2A, 20V | 5.6V @ 13mA | 79 nC @ 18 V | +23V, -7V | 2792 pF @ 400 V | - | 535W (Tc) | -55°C ~ 175°C (TJ) | - | - | Surface Mount | PG-HSOF-8-2 | 8-PowerSFN | https://www.digikey.com/en/products/detail/infineon-technologies/IMT65R015M2HXUMA1/25902066
https://www.rohm.com/datasheet?p=SCT3060AL&dist=Digi-key&media=referral&campaign=Digi-key | //mm.digikey.com/Volume0/opasdata/d220001/medias/images/6311/846%7ETO247N%7E%7E3.jpg | SCT3060ALGC11-ND | SCT3060ALGC11 | Rohm Semiconductor | Rohm Semiconductor | SICFET N-CH 650V 39A TO247N | 603 | 15.35 | 0 | 1 | Tube | - | Active | N-Channel | SiCFET (Silicon Carbide) | 650 V | 39A (Tc) | 18V | 78mOhm @ 13A, 18V | 5.6V @ 6.67mA | 58 nC @ 18 V | +22V, -4V | 852 pF @ 500 V | - | 165W (Tc) | 175°C (TJ) | - | - | Through Hole | TO-247N | TO-247-3 | https://www.digikey.com/en/products/detail/rohm-semiconductor/SCT3060ALGC11/6204897
https://www.infineon.com/assets/row/public/documents/24/49/infineon-imza65r015m2h-datasheet-en.pdf | //mm.digikey.com/Volume0/opasdata/d220001/medias/images/6530/MFG_448%7EPPG-TO247-4-8%7E%7E4.jpg | 448-IMZA65R015M2HXKSA1-ND | IMZA65R015M2HXKSA1 | Infineon Technologies | Infineon Technologies | SILICON CARBIDE MOSFET | 700 | 16.63 | 0 | 1 | Tube | CoolSiC™ Gen 2 | Active | N-Channel | SiCFET (Silicon Carbide) | 650 V | 103A (Tc) | 15V, 20V | 13.2mOhm @ 64.2A, 20V | 5.6V @ 13mA | 79 nC @ 18 V | +23V, -7V | 2792 pF @ 400 V | - | 341W (Tc) | -55°C ~ 175°C (TJ) | - | - | Through Hole | PG-TO247-4-8 | TO-247-4 | https://www.digikey.com/en/products/detail/infineon-technologies/IMZA65R015M2HXKSA1/22157812
https://assets.wolfspeed.com/uploads/2023/10/Wolfspeed_C3M0025065L_data_sheet.pdf | //mm.digikey.com/Volume0/opasdata/d220001/medias/images/6532/MFG_1697%7ETOLL%7E%7E8.jpg | 1697-C3M0025065L-TR-ND,1697-C3M0025065L-TRCT-ND,1697-C3M0025065L-TRDKR-ND | C3M0025065L-TR | Wolfspeed, Inc. | Wolfspeed, Inc. | SIC, MOSFET, 25M, 650V, TOLL, T& | 1375 | 20.84 | 0 | 1 | Tape & Reel (TR),Cut Tape (CT),Digi-Reel® | C3M™ | Active | N-Channel | SiCFET (Silicon Carbide) | 650 V | 77A (Tc) | 15V | 34mOhm @ 33.5A, 15V | 3.6V @ 9.22mA | 111 nC @ 15 V | -8V, +19V | 2970 pF @ 400 V | - | 326W (Tc) | -40°C ~ 175°C (TJ) | - | - | Surface Mount | TOLL | 8-PowerSFN | https://www.digikey.com/en/products/detail/wolfspeed-inc/C3M0025065L-TR/21679325
https://assets.wolfspeed.com/uploads/2024/01/Wolfspeed_C3M0025065K_data_sheet.pdf | //mm.digikey.com/Volume0/opasdata/d220001/medias/images/5706/MFG_1697_C3M0065100K.jpg | 1697-C3M0025065K-ND | C3M0025065K | Wolfspeed, Inc. | Wolfspeed, Inc. | GEN 3 650V 25 M SIC MOSFET | 886 | 20.84 | 0 | 1 | Tube | C3M™ | Active | N-Channel | SiCFET (Silicon Carbide) | 650 V | 97A (Tc) | 15V | 34mOhm @ 33.5A, 15V | 3.6V @ 9.22mA | 112 nC @ 15 V | +19V, -8V | 2980 pF @ 600 V | - | 326W (Tc) | -40°C ~ 175°C (TJ) | - | - | Through Hole | TO-247-4L | TO-247-4 | https://www.digikey.com/en/products/detail/wolfspeed-inc/C3M0025065K/13670509
https://www.infineon.com/dgdl/Infineon-IMZA65R010M2H-DataSheet-v01_00-EN.pdf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 | //mm.digikey.com/Volume0/opasdata/d220001/medias/images/6530/MFG_448%7EPPG-TO247-4-8%7E%7E4.jpg | 448-IMZA65R010M2HXKSA1-ND | IMZA65R010M2HXKSA1 | Infineon Technologies | Infineon Technologies | IMZA65R010M2HXKSA1 | 266 | 21.28 | 0 | 1 | Tube | CoolSiC™ | Active | N-Channel | SiCFET (Silicon Carbide) | 650 V | 144A (Tc) | 15V, 20V | 9.1mOhm @ 92.1A, 20V | 5.6V @ 18.7mA | 112 nC @ 18 V | +23V, -7V | 4001 pF @ 400 V | - | 440W (Tc) | -55°C ~ 175°C (TJ) | - | - | Through Hole | PG-TO247-4-8 | TO-247-4 | https://www.digikey.com/en/products/detail/infineon-technologies/IMZA65R010M2HXKSA1/25664321
https://www.st.com/resource/en/datasheet/scth90n65g2v-7.pdf | //mm.digikey.com/Volume0/opasdata/d220001/medias/images/764/Rohm-TO-263-7.jpg | 497-18352-2-ND,497-18352-1-ND,497-18352-6-ND | SCTH90N65G2V-7 | STMicroelectronics | STMicroelectronics | SICFET N-CH 650V 90A H2PAK-7 | 899 | 23.96 | 0 | 1 | Tape & Reel (TR),Cut Tape (CT),Digi-Reel® | - | Last Time Buy | N-Channel | SiCFET (Silicon Carbide) | 650 V | 90A (Tc) | 18V | 26mOhm @ 50A, 18V | 5V @ 1mA | 157 nC @ 18 V | +22V, -10V | 3300 pF @ 400 V | - | 330W (Tc) | -55°C ~ 175°C (TJ) | - | - | Surface Mount | H2PAK-7 | TO-263-8, D2PAK (7 Leads + Tab), TO-263CA | https://www.digikey.com/en/products/detail/stmicroelectronics/SCTH90N65G2V-7/9805816
//mm.digikey.com/Volume0/opasdata/d220001/medias/docus/6144/IMW65R007M2H.pdf | //mm.digikey.com/Volume0/opasdata/d220001/medias/images/6530/MFG_448%7EPPG-TO247-3-U06%7E%7E3.jpg | 448-IMW65R007M2HXKSA1-ND | IMW65R007M2HXKSA1 | Infineon Technologies | Infineon Technologies | SILICON CARBIDE MOSFET | 1028 | 27.79 | 0 | 1 | Tube | CoolSiC™ | Active | N-Channel | SiCFET (Silicon Carbide) | 650 V | 171A (Tc) | 15V, 20V | 6.1mOhm @ 146.3A, 20V | 5.6V @ 29.7mA | 179 nC @ 18 V | +23V, -7V | 6359 pF @ 400 V | - | 625W (Tc) | -55°C ~ 175°C (TJ) | - | - | Through Hole | PG-TO247-3-U06 | TO-247-3 | https://www.digikey.com/en/products/detail/infineon-technologies/IMW65R007M2HXKSA1/22157513
https://www.onsemi.com/pdf/datasheet/ntbg015n065sc1-d.pdf | //mm.digikey.com/Volume0/opasdata/d220001/medias/images/447/MFG_D2PAK-7.jpg | 5556-NTBG015N065SC1TR-ND,5556-NTBG015N065SC1CT-ND,5556-NTBG015N065SC1DKR-ND | NTBG015N065SC1 | onsemi | onsemi | SILICON CARBIDE MOSFET, NCHANNEL | 2967 | 28.15 | 0 | 1 | Tape & Reel (TR),Cut Tape (CT),Digi-Reel® | - | Active | N-Channel | SiCFET (Silicon Carbide) | 650 V | 145A (Tc) | 15V, 18V | 18mOhm @ 75A, 18V | 4.3V @ 25mA | 283 nC @ 18 V | +22V, -8V | 4689 pF @ 325 V | - | 500W (Tc) | -55°C ~ 175°C (TJ) | - | - | Surface Mount | D2PAK-7 | TO-263-8, D2PAK (7 Leads + Tab), TO-263CA | https://www.digikey.com/en/products/detail/onsemi/NTBG015N065SC1/14545439
https://www.infineon.com/assets/row/public/documents/24/49/infineon-imbg65r007m2h-datasheet-en.pdf | //mm.digikey.com/Volume0/opasdata/d220001/medias/images/6167/448%7EPPG-TO263-7-12%7E%7E7.jpg | 448-IMBG65R007M2HXTMA1TR-ND,448-IMBG65R007M2HXTMA1CT-ND,448-IMBG65R007M2HXTMA1DKR-ND | IMBG65R007M2HXTMA1 | Infineon Technologies | Infineon Technologies | SICFET N-CH 650V 238A TO263-7 | 575 | 28.16 | 0 | 1 | Tape & Reel (TR),Cut Tape (CT),Digi-Reel® | CoolSiC™ Gen 2 | Active | N-Channel | SiCFET (Silicon Carbide) | 650 V | 238A (Tc) | 15V, 20V | 8.5mOhm @ 146.3A, 18V | 5.6V @ 2.97mA | 179 nC @ 18 V | +23V, -7V | 6359 pF @ 400 V | - | 789W (Tc) | -55°C ~ 175°C (TJ) | - | - | Surface Mount | PG-TO263-7-12 | TO-263-8, D2PAK (7 Leads + Tab), TO-263CA | https://www.digikey.com/en/products/detail/infineon-technologies/IMBG65R007M2HXTMA1/22157682
https://www.onsemi.com/download/data-sheet/pdf/nthl015n065sc1-d.pdf | //mm.digikey.com/Volume0/opasdata/d220001/medias/images/6129/488%7E340CX%7E%7E3.jpg | 5556-NTHL015N065SC1-ND | NTHL015N065SC1 | onsemi | onsemi | SILICON CARBIDE (SIC) MOSFET - 1 | 490 | 28.28 | 0 | 1 | Tube | - | Active | N-Channel | SiCFET (Silicon Carbide) | 650 V | 163A (Tc) | 15V, 18V | 18mOhm @ 75A, 18V | 4.3V @ 25mA | 283 nC @ 18 V | +22V, -8V | 4790 pF @ 325 V | - | 643W (Tc) | -55°C ~ 175°C (TJ) | - | - | Through Hole | TO-247-3 | TO-247-3 | https://www.digikey.com/en/products/detail/onsemi/NTHL015N065SC1/17053331
https://www.rohm.com/datasheet?p=SCT3030AL&dist=Digi-key&media=referral&campaign=Digi-key | //mm.digikey.com/Volume0/opasdata/d220001/medias/images/6311/846%7ETO247N%7E%7E3.jpg | SCT3030ALGC11-ND | SCT3030ALGC11 | Rohm Semiconductor | Rohm Semiconductor | SICFET N-CH 650V 70A TO247N | 450 | 28.36 | 0 | 1 | Tube | - | Active | N-Channel | SiCFET (Silicon Carbide) | 650 V | 70A (Tc) | 18V | 39mOhm @ 27A, 18V | 5.6V @ 13.3mA | 104 nC @ 18 V | +22V, -4V | 1526 pF @ 500 V | - | 262W (Tc) | 175°C (TJ) | - | - | Through Hole | TO-247N | TO-247-3 | https://www.digikey.com/en/products/detail/rohm-semiconductor/SCT3030ALGC11/6204894
https://www.rohm.com/datasheet?p=SCT3022AL&dist=Digi-key&media=referral&campaign=Digi-key | //mm.digikey.com/Volume0/opasdata/d220001/medias/images/6311/846%7ETO247N%7E%7E3.jpg | SCT3022ALGC11-ND | SCT3022ALGC11 | Rohm Semiconductor | Rohm Semiconductor | SICFET N-CH 650V 93A TO247N | 650 | 44.17 | 0 | 1 | Tube | - | Active | N-Channel | SiCFET (Silicon Carbide) | 650 V | 93A (Tc) | 18V | 28.6mOhm @ 36A, 18V | 5.6V @ 18.2mA | 133 nC @ 18 V | +22V, -4V | 2208 pF @ 500 V | - | 339W (Tc) | 175°C (TJ) | - | - | Through Hole | TO-247N | TO-247-3 | https://www.digikey.com/en/products/detail/rohm-semiconductor/SCT3022ALGC11/6204893
https://assets.wolfspeed.com/uploads/2024/01/Wolfspeed_C3M0015065K_data_sheet.pdf | //mm.digikey.com/Volume0/opasdata/d220001/medias/images/6529/1697%7ETO247-4%7E%7E4.jpg | 1697-C3M0015065K-ND | C3M0015065K | Wolfspeed, Inc. | Wolfspeed, Inc. | SICFET N-CH 650V 120A TO247-4L | 331 | 51.95 | 0 | 1 | Tube | C3M™ | Active | N-Channel | SiCFET (Silicon Carbide) | 650 V | 120A (Tc) | 15V | 21mOhm @ 55.8A, 15V | 3.6V @ 15.5mA | 188 nC @ 15 V | +15V, -4V | 5011 pF @ 400 V | - | 416W (Tc) | -40°C ~ 175°C (TJ) | - | - | Through Hole | TO-247-4L | TO-247-4 | https://www.digikey.com/en/products/detail/wolfspeed-inc/C3M0015065K/12525323
https://assets.wolfspeed.com/uploads/2024/01/Wolfspeed_C3M0015065D_data_sheet.pdf | //mm.digikey.com/Volume0/opasdata/d220001/medias/images/5706/MFG_1697_C2D10120D.jpg | 1697-C3M0015065D-ND | C3M0015065D | Wolfspeed, Inc. | Wolfspeed, Inc. | SICFET N-CH 650V 120A TO247-3 | 305 | 51.95 | 0 | 1 | Tube | C3M™ | Active | N-Channel | SiCFET (Silicon Carbide) | 650 V | 120A (Tc) | 15V | 21mOhm @ 55.8A, 15V | 3.6V @ 15.5mA | 188 nC @ 15 V | +15V, -4V | 5011 pF @ 400 V | - | 416W (Tc) | -40°C ~ 175°C (TJ) | - | - | Through Hole | TO-247-3 | TO-247-3 | https://www.digikey.com/en/products/detail/wolfspeed-inc/C3M0015065D/12525331
https://www.infineon.com/assets/row/public/documents/24/49/infineon-imlt65r060m2h-datasheet-en.pdf | //mm.digikey.com/Volume0/opasdata/d220001/medias/images/6536/MFG_448%7EP-PG-HDSOP-16-6%7E%7E16.jpg | 448-IMLT65R060M2HXTMA1TR-ND,448-IMLT65R060M2HXTMA1CT-ND,448-IMLT65R060M2HXTMA1DKR-ND | IMLT65R060M2HXTMA1 | Infineon Technologies | Infineon Technologies | SICFET N-CH 650V 40A HDSOP-16 | 1754 | 6.22 | 0 | 1 | Tape & Reel (TR),Cut Tape (CT),Digi-Reel® | CoolSiC™ Gen 2 | Active | N-Channel | SiCFET (Silicon Carbide) | 650 V | 40A (Tc) | 15V, 18V | 73mOhm @ 15.4A, 18V | 5.6V @ 3.1mA | 18 nC @ 18 V | +23V, -7V | 669 pF @ 400 V | - | 200W (Tc) | -55°C ~ 175°C (TJ) | - | - | Surface Mount | PG-HDSOP-16-6 | 16-PowerSOP Module | https://www.digikey.com/en/products/detail/infineon-technologies/IMLT65R060M2HXTMA1/23018600
https://www.infineon.com/dgdl/Infineon-IMT65R060M2H-DataSheet-v02_02-EN.pdf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 | //mm.digikey.com/Volume0/opasdata/d220001/medias/images/6402/MFG_448%7EPPG-HSOF-8-2%7E%7E8.jpg | 448-IMT65R060M2HXUMA1TR-ND,448-IMT65R060M2HXUMA1CT-ND,448-IMT65R060M2HXUMA1DKR-ND | IMT65R060M2HXUMA1 | Infineon Technologies | Infineon Technologies | SILICON CARBIDE MOSFET | 3230 | 6.3 | 0 | 1 | Tape & Reel (TR),Cut Tape (CT),Digi-Reel® | CoolSiC™ | Active | N-Channel | SiCFET (Silicon Carbide) | 650 V | 41.4A (Tc) | 15V, 20V | 55mOhm @ 15.4A, 20V | 5.6V @ 3.1mA | 19 nC @ 18 V | +23V, -7V | 669 pF @ 400 V | - | 208W (Tc) | -55°C ~ 175°C (TJ) | - | - | Surface Mount | PG-HSOF-8-2 | 8-PowerSFN | https://www.digikey.com/en/products/detail/infineon-technologies/IMT65R060M2HXUMA1/25902331
https://www.infineon.com/dgdl/Infineon-IMZA65R107M1H-DataSheet-v02_00-EN.pdf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 | //mm.digikey.com/Volume0/opasdata/d220001/medias/images/6311/448%7EPPG-TO247-3-41%7E%7E3.jpg | 448-IMZA65R107M1HXKSA1-ND | IMZA65R107M1HXKSA1 | Infineon Technologies | Infineon Technologies | MOSFET 650V NCH SIC TRENCH | 102 | 6.43 | 0 | 1 | Tube | CoolSIC™ M1 | Active | N-Channel | SiCFET (Silicon Carbide) | 650 V | 20A (Tc) | 18V | 142mOhm @ 8.9A, 18V | 5.7V @ 3mA | 15 nC @ 18 V | +23V, -5V | 496 pF @ 400 V | - | 75W (Tc) | -55°C ~ 150°C (TJ) | - | - | Through Hole | PG-TO247-3-41 | TO-247-3 | https://www.digikey.com/en/products/detail/infineon-technologies/IMZA65R107M1HXKSA1/11483563
https://www.infineon.com/assets/row/public/documents/24/49/infineon-imlt65r050m2h-datasheet-en.pdf | //mm.digikey.com/Volume0/opasdata/d220001/medias/images/6536/MFG_448%7EP-PG-HDSOP-16-6%7E%7E16.jpg | 448-IMLT65R050M2HXTMA1TR-ND,448-IMLT65R050M2HXTMA1CT-ND,448-IMLT65R050M2HXTMA1DKR-ND | IMLT65R050M2HXTMA1 | Infineon Technologies | Infineon Technologies | SICFET N-CH 650V 47A HDSOP-16 | 1680 | 6.89 | 0 | 1 | Tape & Reel (TR),Cut Tape (CT),Digi-Reel® | CoolSiC™ Gen 2 | Active | N-Channel | SiCFET (Silicon Carbide) | 650 V | 47A (Tc) | 15V, 18V | 62mOhm @ 18.2A, 18V | 5.6V @ 3.7mA | 22 nC @ 18 V | +23V, -7V | 790 pF @ 400 V | - | 227W (Tc) | -55°C ~ 175°C (TJ) | - | - | Surface Mount | PG-HDSOP-16-6 | 16-PowerSOP Module | https://www.digikey.com/en/products/detail/infineon-technologies/IMLT65R050M2HXTMA1/23018607
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

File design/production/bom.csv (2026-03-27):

Designator | Footprint | Quantity | Value | LCSC Part #
C_CSF1 | 402 | 1 | 82p | C107011
C1, C11, C20, C21 | 402 | 4 | 4.7u | C2858031
C10, C12, C2, C3, C4, C5, C8, C9, CBOOT1, CBOOT2, CFF1, CFF2, COUT1, COUT5 | 402 | 14 | 100n | C1525
C13, C15, C26, C7 | 402 | 4 | 1u | C52923
C14, C16 | 402 | 2 | 5u | C29266
C17, C18, CIN1, CIN2, CIN3, CIN4 | 1206 | 6 | 4.7u | C29823
C19 | 603 | 1 | 2.2n | C1604
C22, C25 | 402 | 2 | 0.1u | C1525
C23 | 1206 | 1 | 0.1u | C24497
C24, C27 | 402 | 2 | 1n | C1523
C28 | 1206 | 1 | 68n | C711038
C29 | 402 | 1 | 0.1n | C343055
C30 | 603 | 1 | 22u | C60077
C32, C33, C34 | 402 | 3 | 10p | C32949
C6 | 402 | 1 | 10n | C1524
CBANK1, CBANK2, CBANK3, CBANK4, CBANK5 | 2220 | 5 | 1u | C784102
CHF1, CHF2 | 805 | 2 | 220n | C5378
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

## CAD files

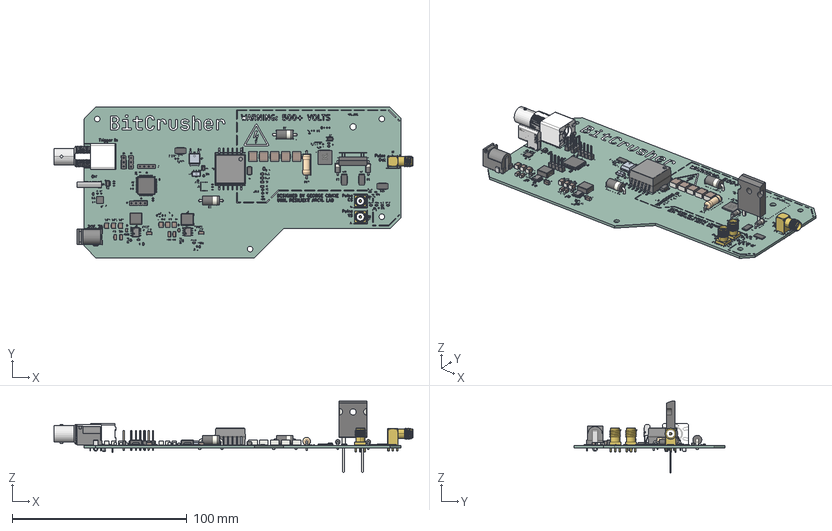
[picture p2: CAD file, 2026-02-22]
case/BitCrusher.step
205.6 x 86.2 x 41.1 mm
C_1206_3216Metric x 6
R_0402_1005Metric x 6
R_0603_1608Metric x 20
Same_Sky_PJ-002BH
R_2512_6332Metric x 4
C_2220_5750Metric x 5
C_1210_3225Metric x 6
C_0402_1005Metric x 38
C_0603_1608Metric
D_SMA
C_0805_2012Metric x 2
SOT-23-6
ESOP-8_L4.9-W3.9-P1.27-LS6.0-BL-EP-1 x 2
D_SOD-882 x 2
PinHeader_1x04_P2.54mm_Vertical x 2
D_DO-201AD_P12.70mm_Horizontal x 2
R_0805_2012Metric x 5
R_Axial_DIN0414_L11.9mm_D4.5mm_P15.24mm_Horizontal
ANT-TH_KH-BNC50-3511
L_TechFuse_SL0630 x 2
PinHeader_1x03_P2.54mm_Vertical x 2
D_DO-41_SOD81_P7.62mm_Horizontal x 2
SMA-TH_BWSMA-KE-Z001 x 2
TO-247-2_Vertical
QFN-16-1EP_4x4mm_P0.65mm_EP2.1x2.1mm
BitCrusher 1.79.1
TYPE-C-TH_TYPE-C-14P-CC-2.6
LQFP-64_10x10mm_P0.5mm
D_SOD-123
SOT8074-1
BitCrusher 1.114.1
D_SOD-323
SMA-TH_BWSMA-KWE-Z001
PinsArrayLR
BitCrusher_silkscreen
BitCrusher_PCB

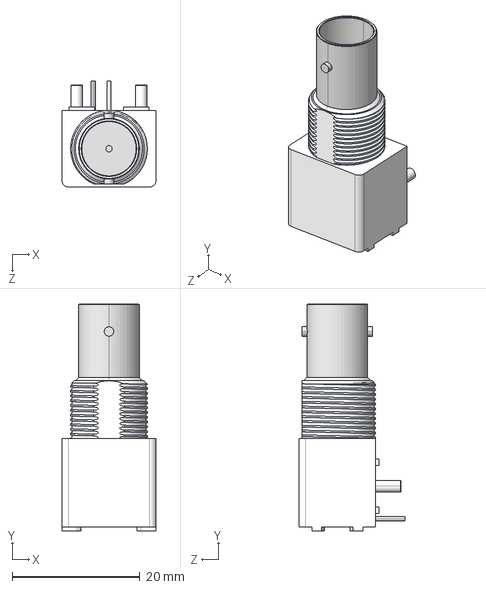
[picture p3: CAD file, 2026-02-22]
design/3d-models/ANT-TH_KH-BNC50-3511.step
14.7 x 35.5 x 16.6 mm

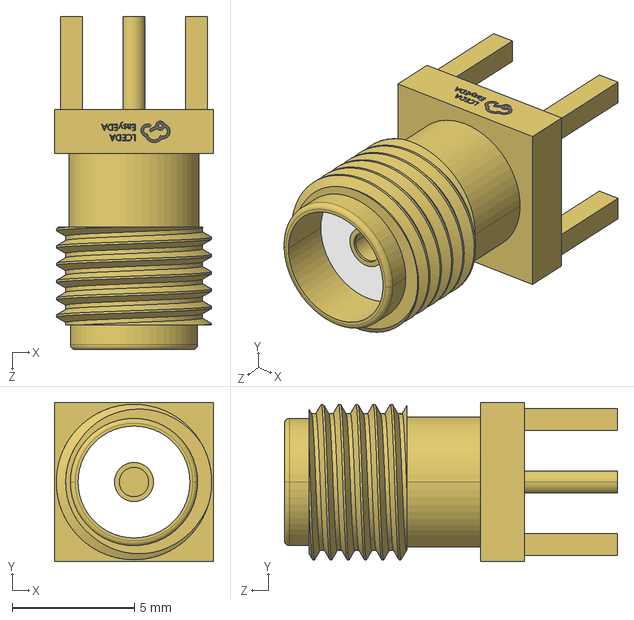
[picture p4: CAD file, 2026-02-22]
design/3d-models/SMA-TH_BWSMA-KE-Z001.step
6.50 x 6.50 x 13.6 mm

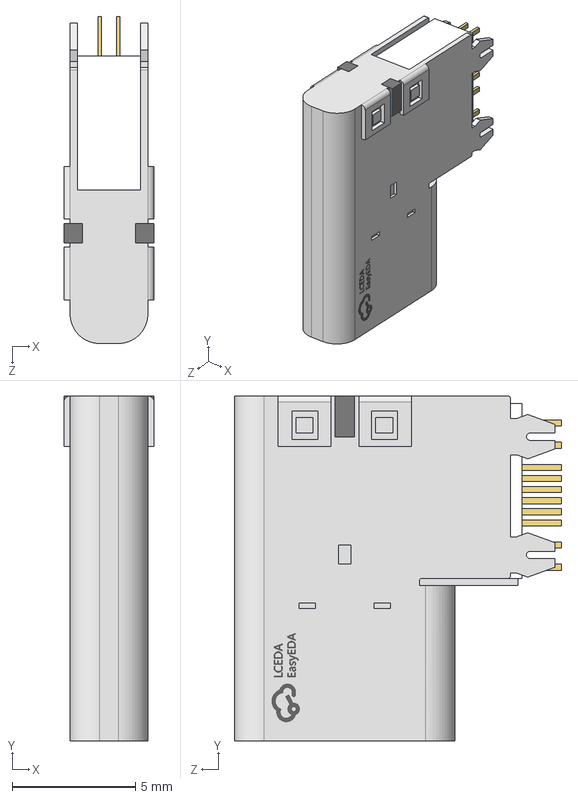
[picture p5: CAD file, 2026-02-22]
design/3d-models/TYPE-C-TH_TYPE-C-14P-CC-2.6.step
3.66 x 14.0 x 13.3 mm

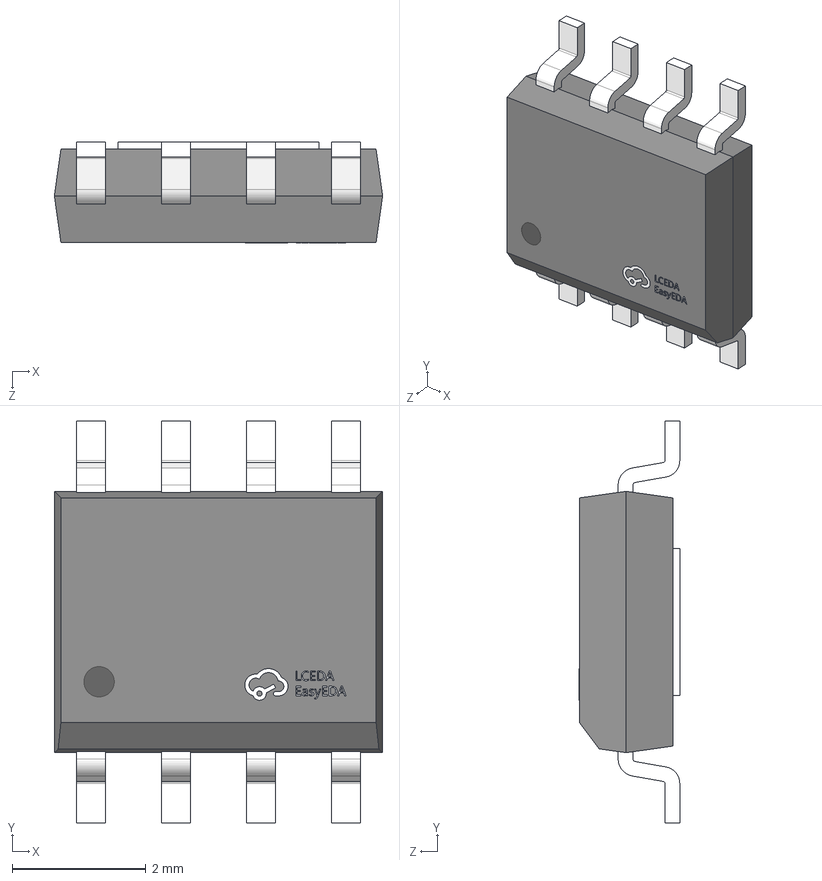
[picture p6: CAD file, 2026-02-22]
design/3d-models/ESOP-8_L4.9-W3.9-P1.27-LS6.0-BL-EP-1.step
4.90 x 6.00 x 1.50 mm

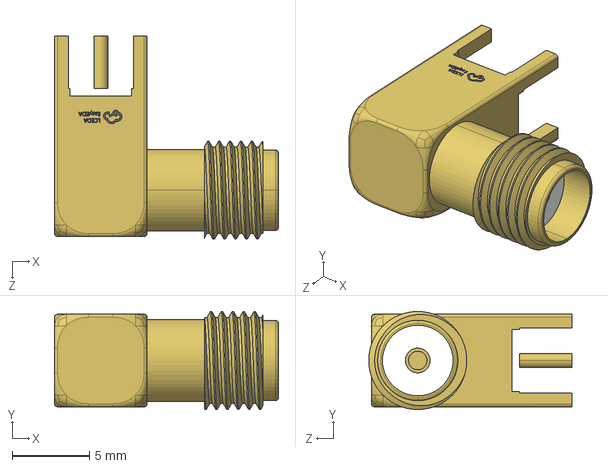
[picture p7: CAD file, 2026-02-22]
design/3d-models/SMA-TH_BWSMA-KWE-Z001.step
14.5 x 6.35 x 13.2 mm

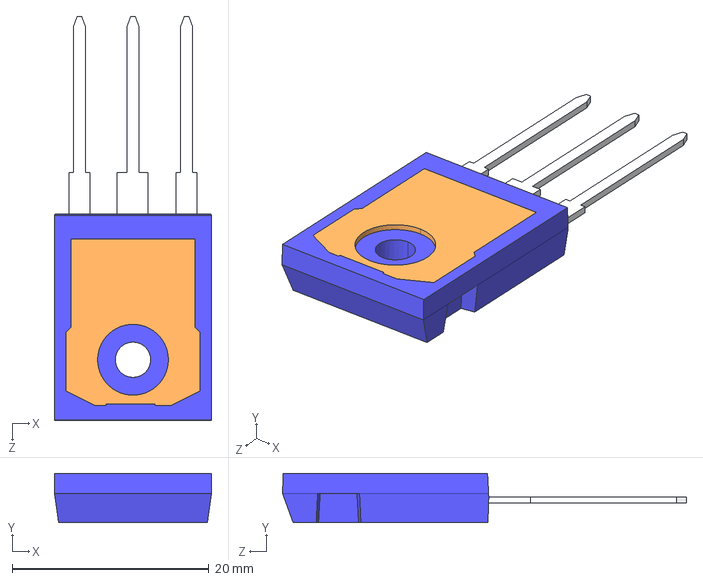
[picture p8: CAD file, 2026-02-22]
design/3d-models/TO-247.STEP
15.9 x 5.02 x 41.0 mm

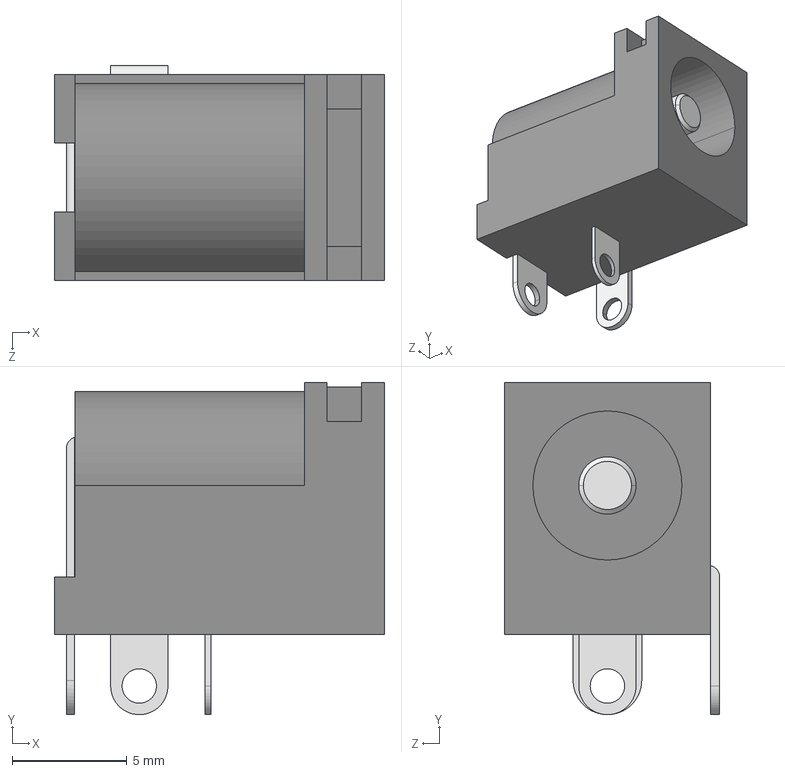
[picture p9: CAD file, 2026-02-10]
design/3d-models/Same_Sky_PJ-002BH.step
14.4 x 14.5 x 9.40 mm

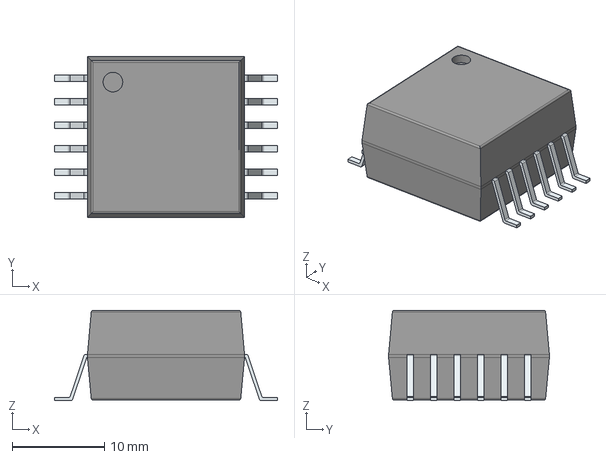
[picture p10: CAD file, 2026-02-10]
design/3d-models/DA2033-ALB.stp
24.1 x 17.4 x 9.78 mm
PinsArrayLR

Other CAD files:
case/Unnamed.FCStd

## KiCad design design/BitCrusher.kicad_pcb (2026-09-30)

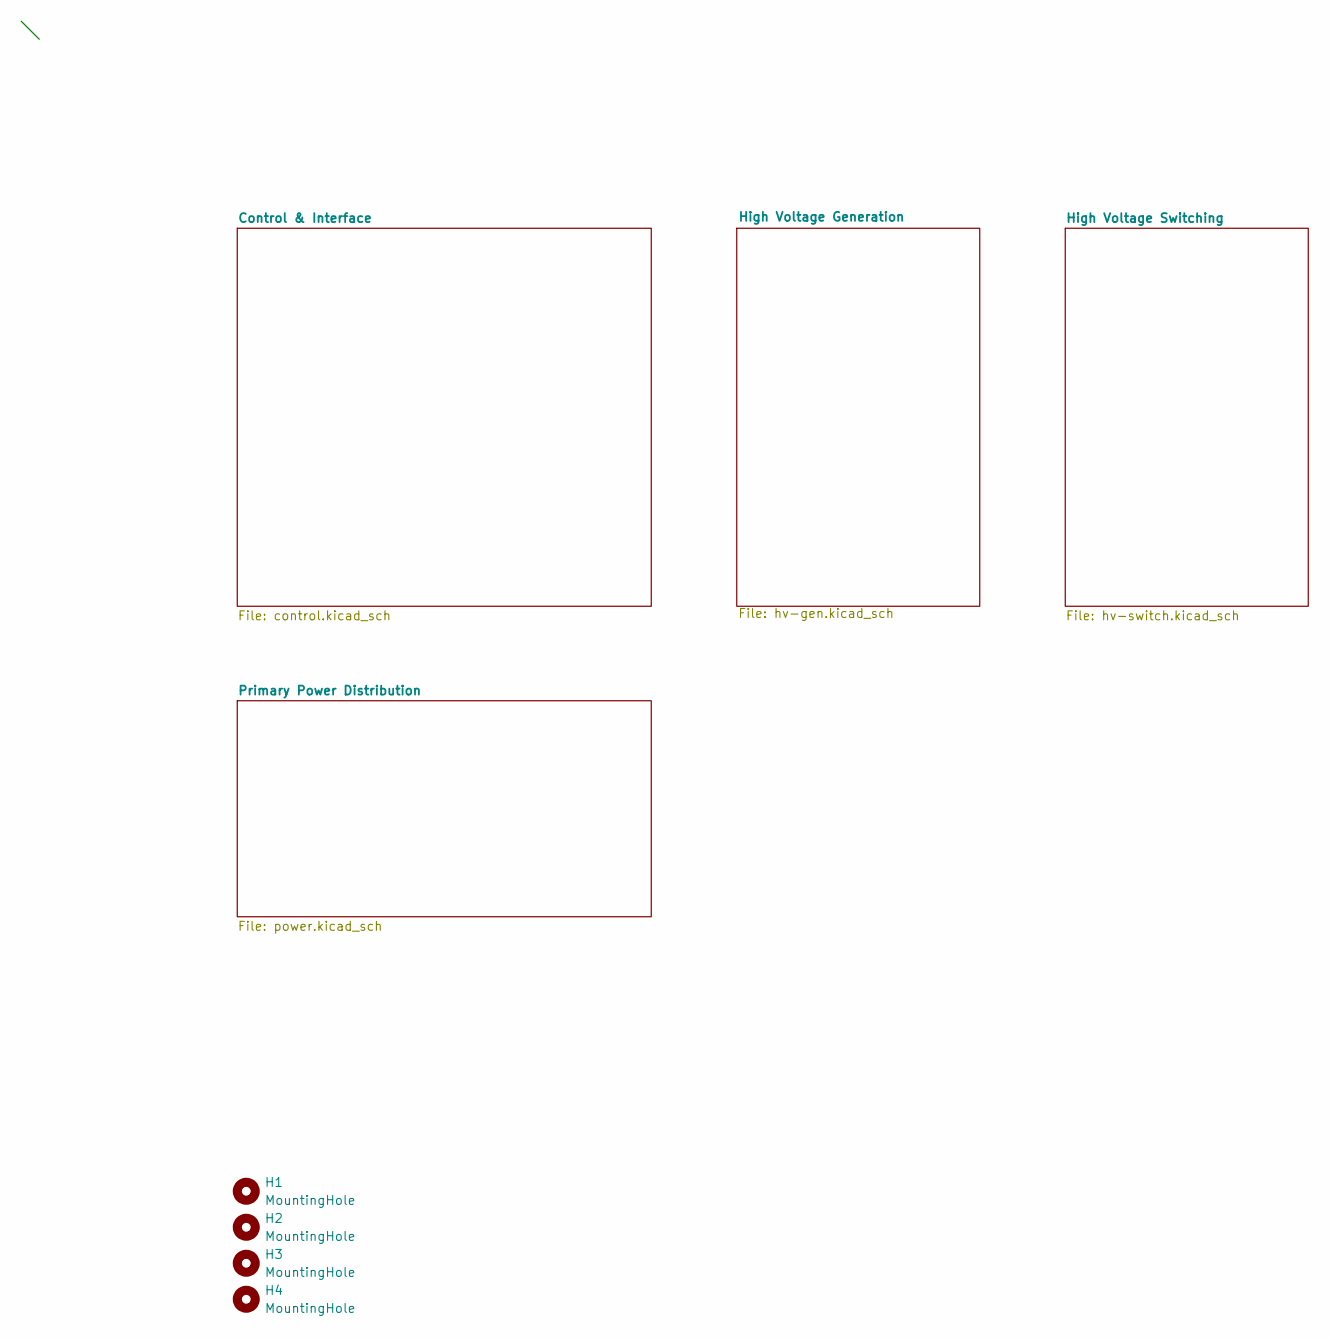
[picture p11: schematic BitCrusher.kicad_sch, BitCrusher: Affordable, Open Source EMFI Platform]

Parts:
H1, H2, H3, H4: MountingHole; MountingHole_3.2mm_M3

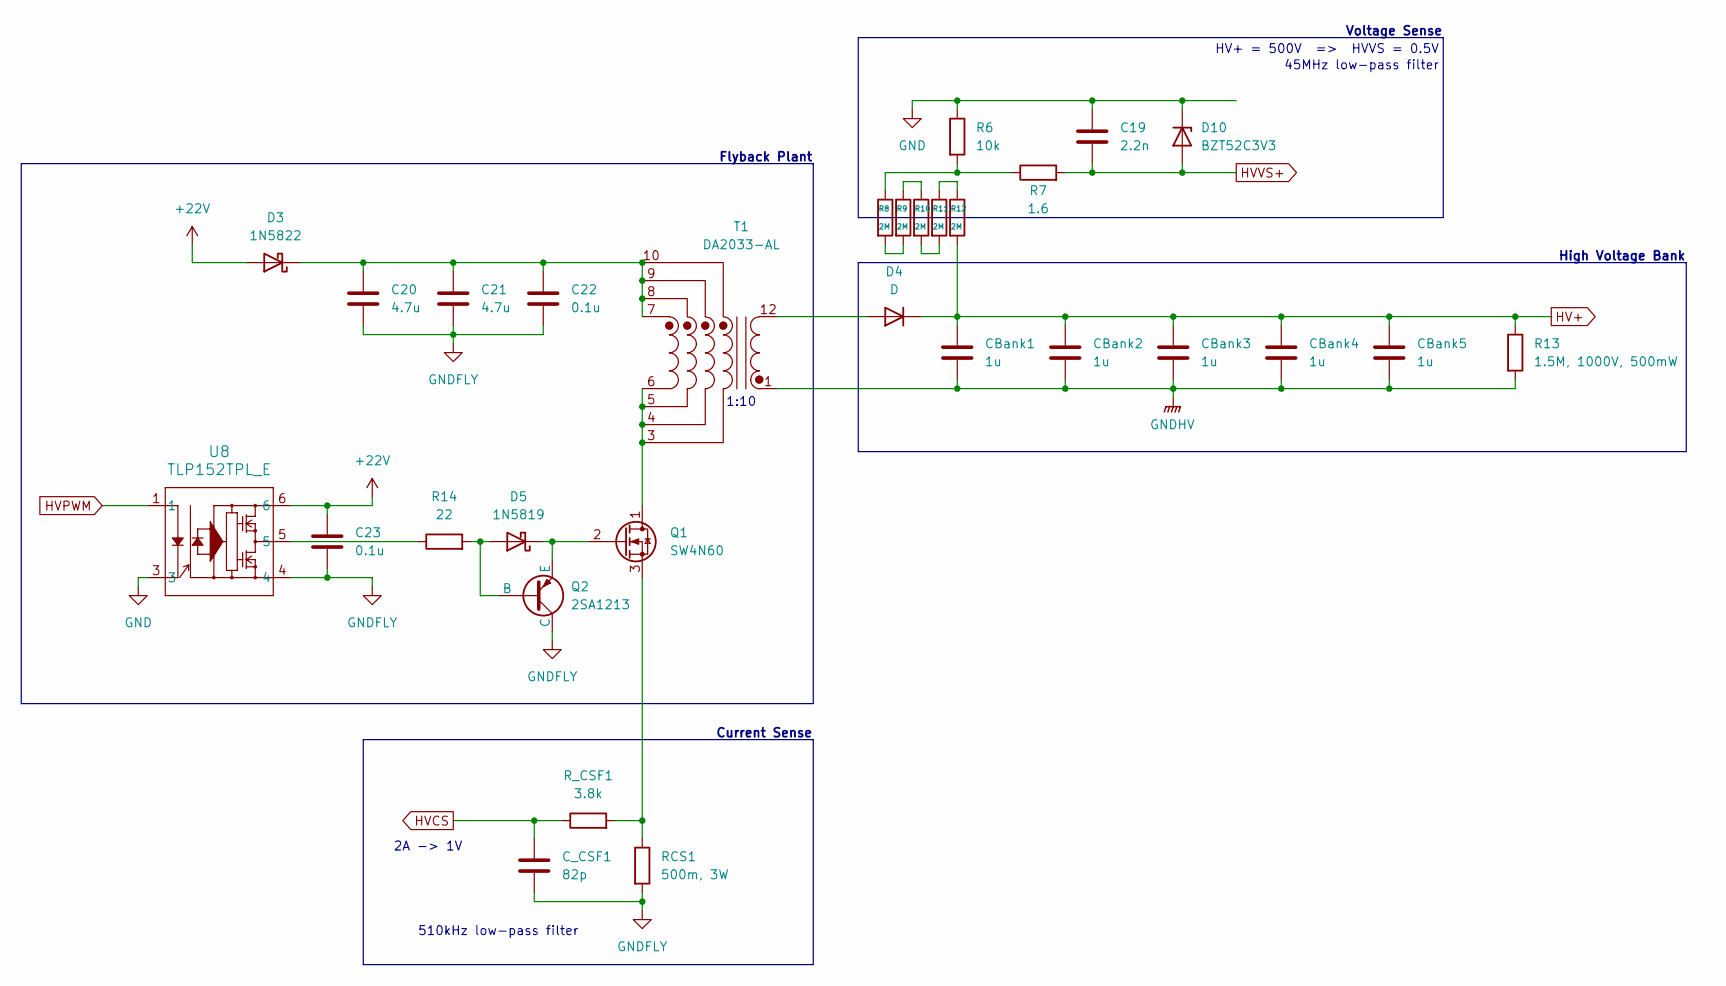
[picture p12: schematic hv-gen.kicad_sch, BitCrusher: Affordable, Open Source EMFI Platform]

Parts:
C19: 2.2n; C_0603_1608Metric
C20, C21: 4.7u; C_0402_1005Metric
C22: 0.1u; C_0402_1005Metric
C23: 0.1u; C_1206_3216Metric
CBank1, CBank2, CBank3, CBank4, CBank5: 1u; C_2220_5750Metric; JLCPCB# C784102
C_CSF1: 82p; C_0402_1005Metric
D3: 1N5822; D_DO-201AD_P12.70mm_Horizontal
D4: D; D_SMA
D5: 1N5819; D_SOD-323
D10: BZT52C3V3; D_SOD-123
Q1: SW4N60
Q2: 2SA1213; SOT-89-3
R6: 10k; R_0603_1608Metric
R7: 1.6; R_0603_1608Metric
R8, R9, R10, R11, R12: 2M; R_0805_2012Metric
R13: 1.5M, 1000V, 500mW; R_Axial_DIN0414_L11.9mm_D4.5mm_P15.24mm_Horizontal; JLCPCB# C30187384
R14: 22; R_0805_2012Metric
RCS1: 500m, 3W; R_2512_6332Metric
R_CSF1: 3.8k; R_0402_1005Metric
T1: DA2033-AL; SOP254P2413X978-12N
U8: TLP152TPL_E; TLP152_4P55X3P7_TOS

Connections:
+22V: C23.1, D3.2 (A), U8.6; also elsewhere on the board
GND: C19.1, D10.1 (K), R6.1, U8.3; also elsewhere on the board
GNDFLY: C20.2, C21.2, C22.2, C23.2, C_CSF1.2, Q2.C, RCS1.2, U8.4; also elsewhere on the board
HV+: CBank1.1, CBank2.1, CBank3.1, CBank4.1, CBank5.1, D4.1 (K), R12.2, R13.1; also elsewhere on the board
HVCS: C_CSF1.1, R_CSF1.1; also elsewhere on the board
HVPWM: U8.1; also elsewhere on the board
HVVS+: C19.2, D10.2 (A), R7.2; also elsewhere on the board
unnamed: C20.1, C21.1, C22.1, D3.1 (K), T1.7, T1.8, T1.9, T1.10
unnamed: D4.2 (A), T1.12
unnamed: D5.2 (A), Q2.B, R14.2
unnamed: D5.1 (K), Q1.2 (G), Q2.E
unnamed: Q1.1 (D), T1.3, T1.4, T1.5, T1.6
unnamed: Q1.3 (S), RCS1.1, R_CSF1.2
unnamed: R6.2, R7.1, R8.1
unnamed: R8.2, R9.2
unnamed: R9.1, R10.1
unnamed: R10.2, R11.2
unnamed: R11.1, R12.1
unnamed: R14.1, U8.5
PulseCS-: CBank1.2, CBank2.2, CBank3.2, CBank4.2, CBank5.2, R13.2, T1.1; also elsewhere on the board

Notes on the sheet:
High Voltage Bank
510kHz low-pass filter
Flyback Plant
2A -> 1V
1:10
Current Sense
HV+ = 500V => HVVS = 0.5V
Voltage Sense
45MHz low-pass filter

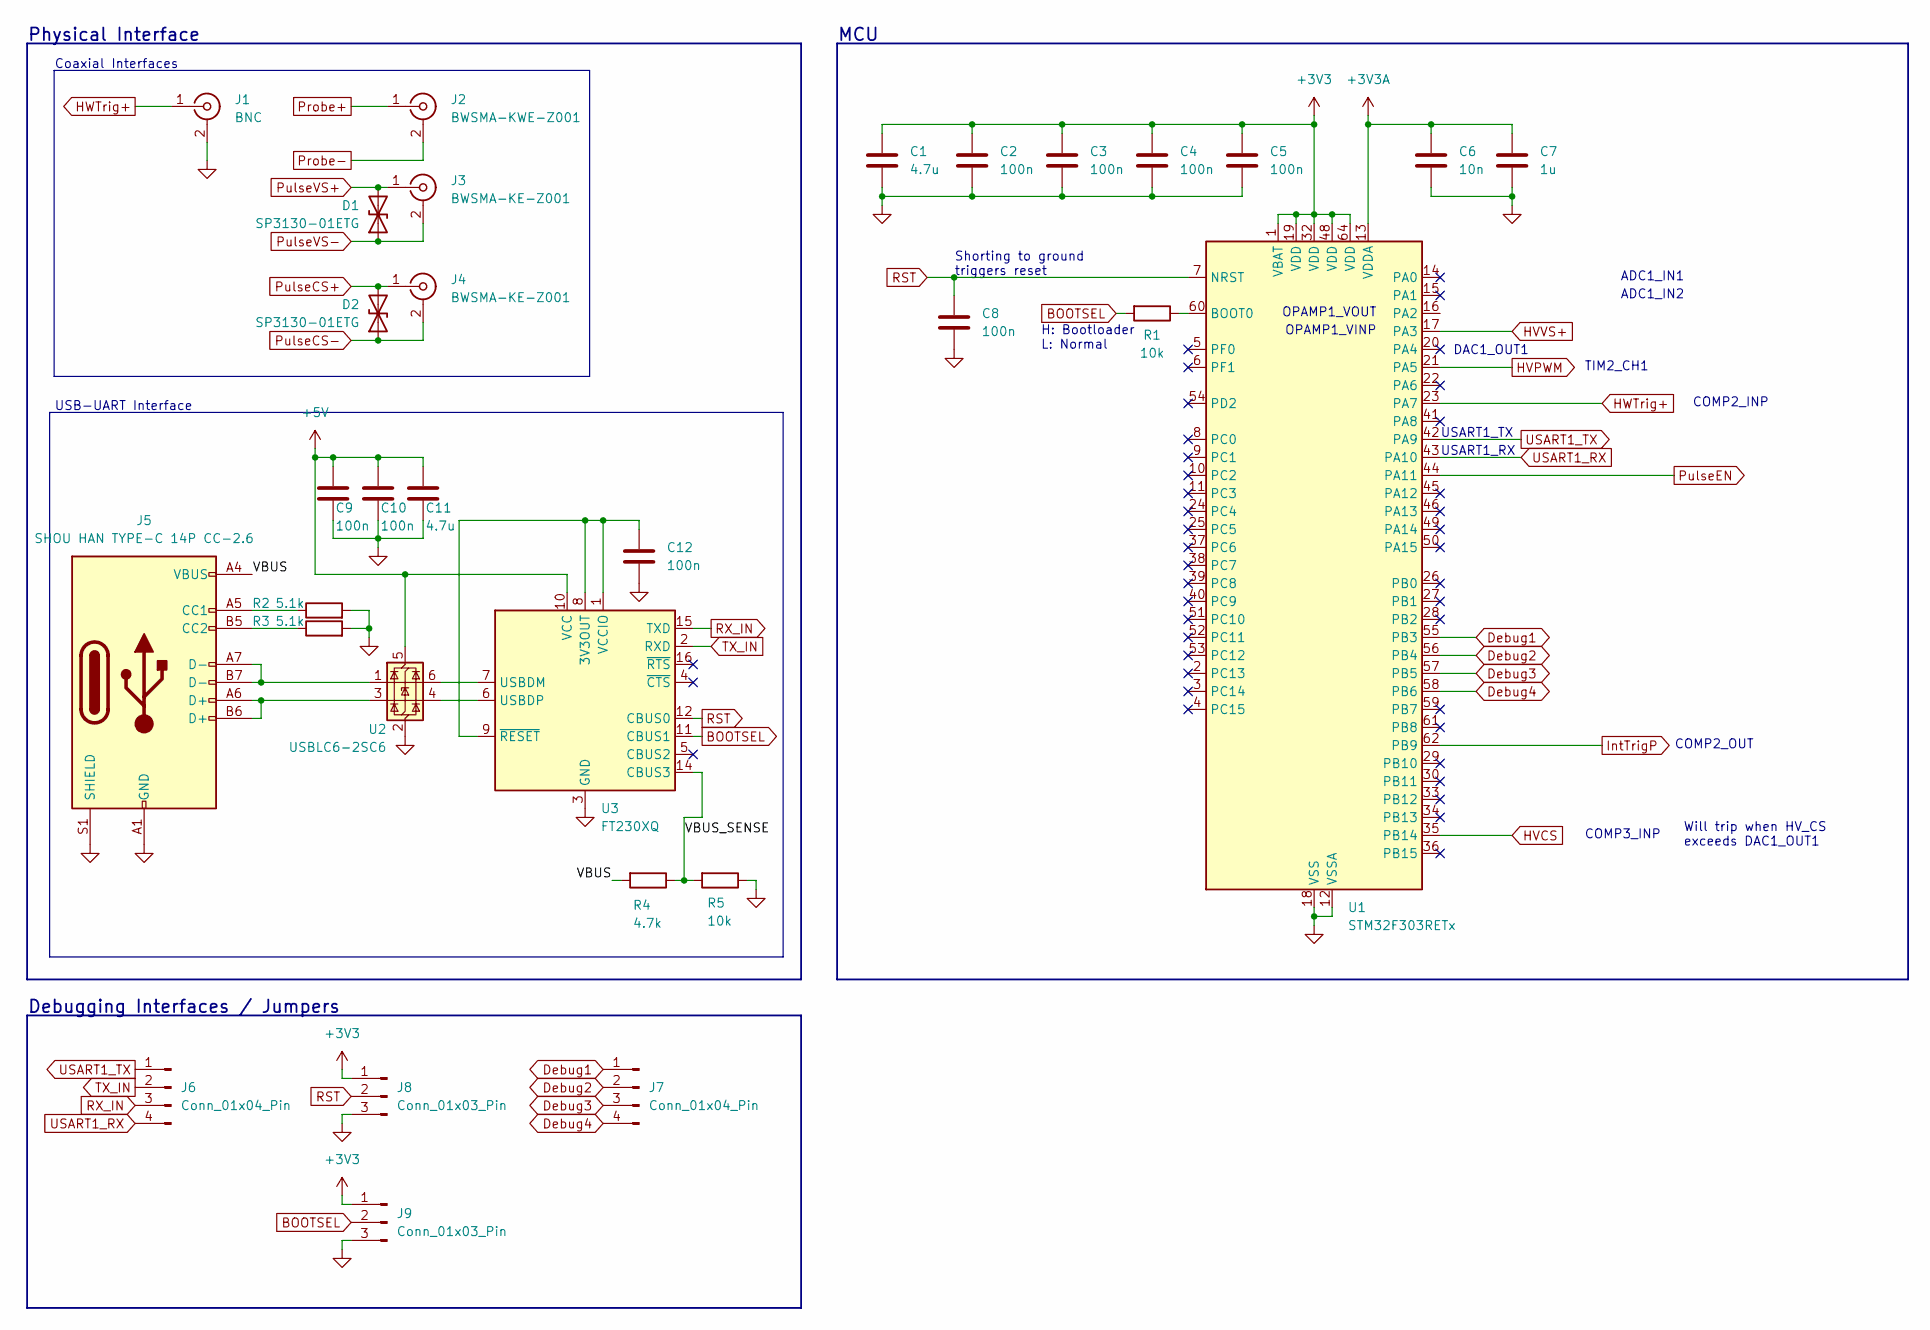
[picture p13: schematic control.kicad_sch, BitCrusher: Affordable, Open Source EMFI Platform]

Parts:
C1, C11: 4.7u; C_0402_1005Metric
C2, C3, C4, C5, C8, C9, C10, C12: 100n; C_0402_1005Metric
C6: 10n; C_0402_1005Metric
C7: 1u; C_0402_1005Metric
D1, D2: SP3130-01ETG; D_SOD-882
J1: BNC; KHBNC503511
J2: BWSMA-KWE-Z001; SMA_BAT_Wireless_BWSMA-KWE-Z001
J3, J4: BWSMA-KE-Z001; SMA_BAT_Wireless_BWSMA-KE-Z001
J5: SHOU HAN TYPE-C 14P CC-2.6; TYPE-C-TH_TYPE-C-14P-CC-2.6
J6, J7: Conn_01x04_Pin; PinHeader_1x04_P2.54mm_Vertical
J8, J9: Conn_01x03_Pin; PinHeader_1x03_P2.54mm_Vertical
R1, R5: 10k; R_0402_1005Metric
R2, R3: 5.1k; R_0603_1608Metric
R4: 4.7k; R_0402_1005Metric
U1: STM32F303RETx; LQFP-64_10x10mm_P0.5mm
U2: USBLC6-2SC6; SOT-23-6
U3: FT230XQ; QFN-16-1EP_4x4mm_P0.65mm_EP2.1x2.1mm

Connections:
+3V3: C1.1, C2.1, C3.1, C4.1, C5.1, C6.1, C7.1, J8.1, J9.1, U1.1 (VBAT), U1.13 (VDDA), U1.19 (VDD), U1.32 (VDD), U1.48 (VDD), U1.64 (VDD); also elsewhere on the board
+5V: C9.1, C10.1, C11.1, U2.5 (VBUS), U3.10 (VCC); also elsewhere on the board
/Control & Interface/VBUS: J5.A4 (VBUS), J5.A9 (VBUS), J5.B4 (VBUS), J5.B9 (VBUS), R4.2
/Control & Interface/VBUS_SENSE: R4.1, R5.2, U3.14 (CBUS3)
BOOTSEL: J9.2, R1.2, U3.11 (CBUS1)
Debug1: J7.1, U1.55 (PB3)
Debug2: J7.2, U1.56 (PB4)
Debug3: J7.3, U1.57 (PB5)
Debug4: J7.4, U1.58 (PB6)
GND: C1.2, C2.2, C3.2, C4.2, C5.2, C6.2, C7.2, C8.2, C9.2, C10.2, C11.2, C12.2, J1.2 (Ext), J5.A1 (GND), J5.A12 (GND), J5.B1 (GND), J5.B12 (GND), J5.S1 (SHIELD), J8.3, J9.3, R2.2, R3.2, R5.1, U1.12 (VSSA), U1.18 (VSS), U1.31 (VSS), U1.47 (VSS), U1.63 (VSS), U2.2 (GND), U3.3 (GND), U3.13 (GND), U3.17 (GND); also elsewhere on the board
HVCS: U1.35 (PB14); also elsewhere on the board
HVPWM: U1.21 (PA5); also elsewhere on the board
HVVS+: U1.17 (PA3); also elsewhere on the board
HWTrig+: J1.1 (In), U1.23 (PA7)
IntTrigP: U1.62 (PB9); also elsewhere on the board
unnamed: J5.A5 (CC1), R2.1
unnamed: J5.B5 (CC2), R3.1
unnamed: J5.A6 (D+), J5.B6 (D+), U2.3 (I/O2)
unnamed: J5.A7 (D-), J5.B7 (D-), U2.1 (I/O1)
unnamed: R1.1, U1.60 (BOOT0)
unnamed: C12.1, U3.1 (VCCIO), U3.8 (3V3OUT), U3.9 (~RESET)
unnamed: U2.6 (I/O1), U3.7 (USBDM)
unnamed: U2.4 (I/O2), U3.6 (USBDP)
Probe+: J2.1 (In); also elsewhere on the board
Probe-: J2.2 (Ext); also elsewhere on the board
PulseCS+: D2.2 (A2), J4.1 (In); also elsewhere on the board
PulseCS-: D1.1 (A1), D2.1 (A1), J3.2 (Ext), J4.2 (Ext); also elsewhere on the board
PulseEN: U1.44 (PA11); also elsewhere on the board
PulseVS+: D1.2 (A2), J3.1 (In); also elsewhere on the board
RST: C8.1, J8.2, U1.7 (NRST), U3.12 (CBUS0)
RX_IN: J6.3, U3.15 (TXD)
TX_IN: J6.2, U3.2 (RXD)
USART1_RX: J6.4, U1.43 (PA10)
USART1_TX: J6.1, U1.42 (PA9)

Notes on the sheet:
OPAMP1_VINP
ADC1_IN2
COMP2_INP
USART1_TX
H: Bootloader L: Normal
TIM2_CH1
ADC1_IN1
MCU
Debugging Interfaces / Jumpers
DAC1_OUT1
COMP2_OUT
Shorting to ground triggers reset
USB-UART Interface
USART1_RX
OPAMP1_VOUT
Coaxial Interfaces
Will trip when HV_CS exceeds DAC1_OUT1
COMP3_INP
Physical Interface

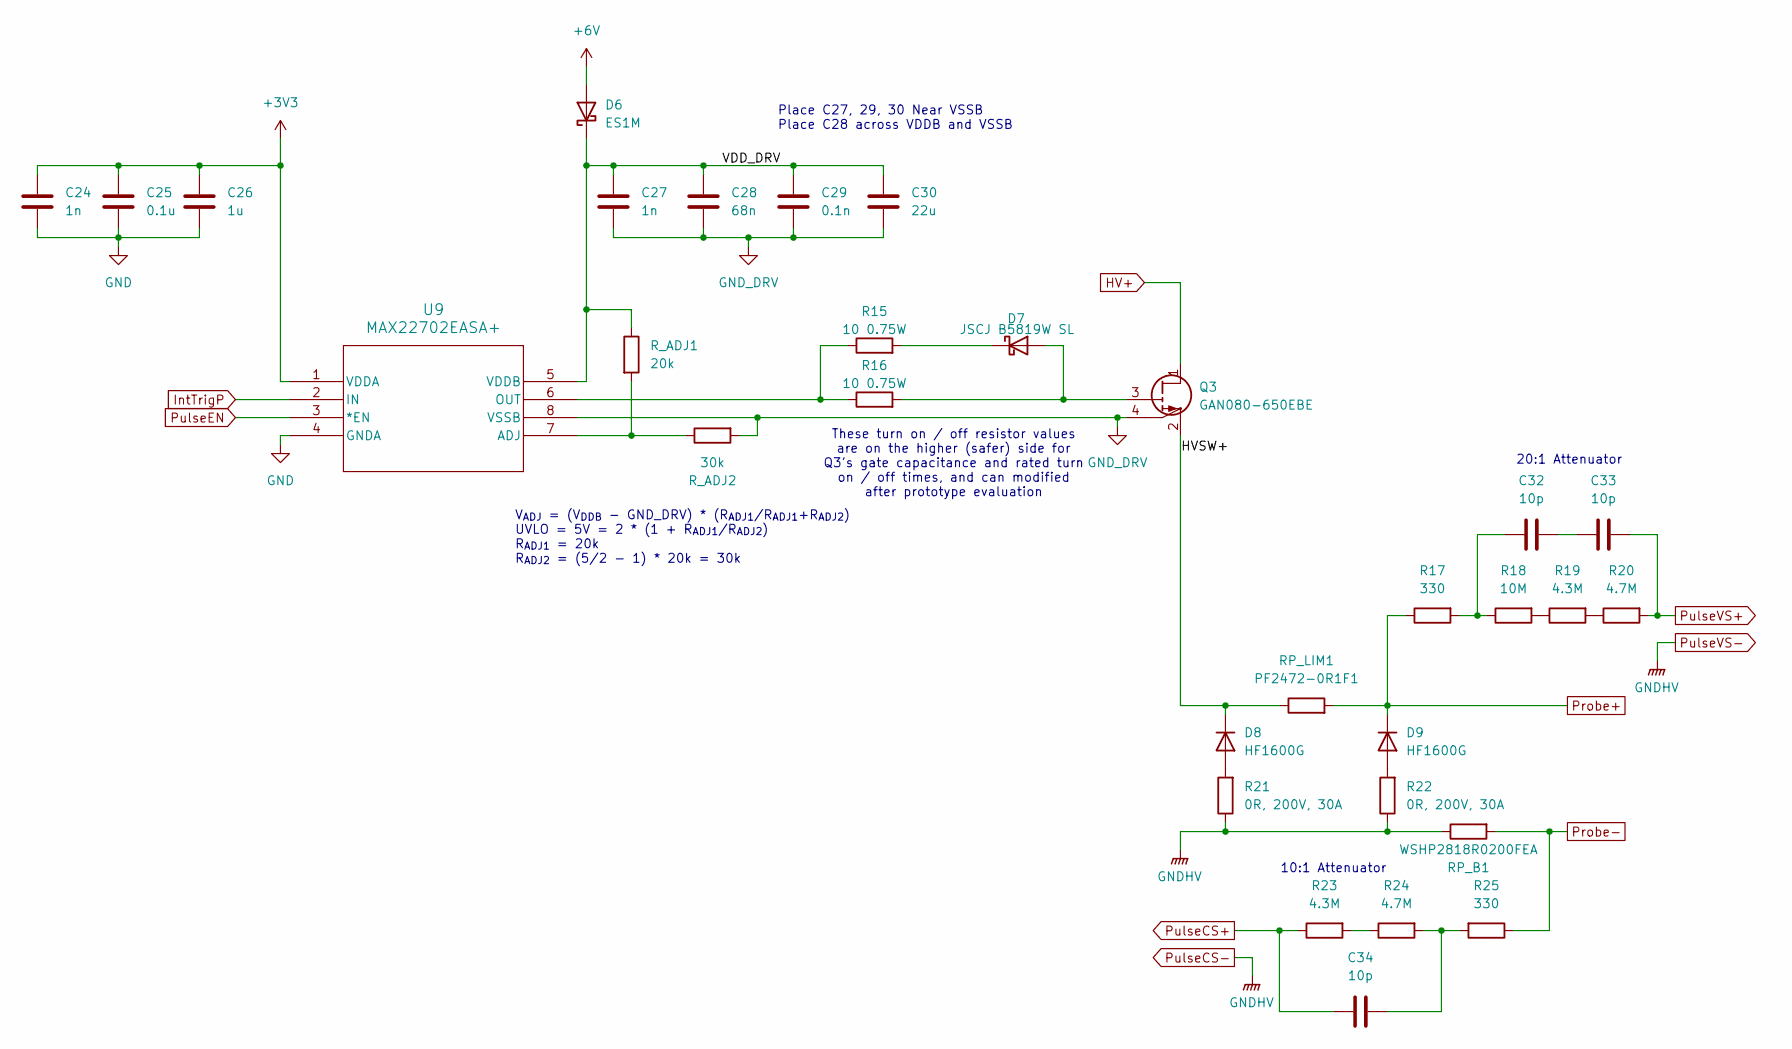
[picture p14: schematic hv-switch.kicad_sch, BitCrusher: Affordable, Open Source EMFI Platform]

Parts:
C24, C27: 1n; C_0402_1005Metric
C25: 0.1u; C_0402_1005Metric
C26: 1u; C_0402_1005Metric
C28: 68n; C_1206_3216Metric
C29: 0.1n; C_0402_1005Metric
C30: 22u; C_0603_1608Metric; JLCPCB# C60077
C32, C33, C34: 10p; C_0402_1005Metric
D6: ES1M; D_SMA
D7: JSCJ B5819W SL; D_SOD-123
D8, D9: HF1600G; D_DO-41_SOD81_P7.62mm_Horizontal
Q3: GAN080-650EBE; GAN080650EBEZ
R15, R16: 10 0.75W; R_1206_3216Metric
R17: 330; R_0603_1608Metric
R18: 10M; R_0603_1608Metric
R19, R23: 4.3M; R_0603_1608Metric
R20, R24: 4.7M; R_0603_1608Metric
R21, R22: 0R, 200V, 30A; R_2512_6332Metric
R25: 330; R_2512_6332Metric
RP_B1: WSHP2818R0200FEA
RP_LIM1: PF2472-0R1F1; TO-247-2_Horizontal_TabDown
R_ADJ1: 20k; R_0402_1005Metric
R_ADJ2: 30k; R_0402_1005Metric
U9: MAX22702EASA+; 21-0041-A_8L

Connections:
+3V3: C24.1, C25.1, C26.1, U9.1 (VDDA); also elsewhere on the board
+6V: D6.2 (A); also elsewhere on the board
/High Voltage Switching/HVSW+: D8.1 (K), Q3.2 (S), RP_LIM1.1
/High Voltage Switching/VDD_DRV: C27.1, C28.1, C29.1, C30.1, D6.1 (K), R_ADJ1.1, U9.5 (VDDB)
GND: C24.2, C25.2, C26.2, U9.4 (GNDA); also elsewhere on the board
GND_DRV: C27.2, C28.2, C29.2, C30.2, Q3.4 (SS), R_ADJ2.2, U9.8 (VSSB)
HV+: Q3.1 (D); also elsewhere on the board
IntTrigP: U9.2 (IN); also elsewhere on the board
unnamed: C32.1, C33.2
unnamed: C32.2, R17.2, R18.1
unnamed: C34.2, R24.2, R25.2
unnamed: D7.2 (A), Q3.3 (G), R16.2
unnamed: D7.1 (K), R15.2
unnamed: D8.2 (A), R21.2
unnamed: D9.2 (A), R22.2
unnamed: R18.2, R19.1
unnamed: R19.2, R20.1
unnamed: R23.2, R24.1
unnamed: R_ADJ1.2, R_ADJ2.1, U9.7 (ADJ)
unnamed: R15.1, R16.1, U9.6 (OUT)
Probe+: D9.1 (K), R17.1, RP_LIM1.2; also elsewhere on the board
Probe-: R25.1, RP_B1.2; also elsewhere on the board
PulseCS+: C34.1, R23.1; also elsewhere on the board
PulseCS-: R21.1, R22.1, RP_B1.1; also elsewhere on the board
PulseEN: U9.3 (*EN); also elsewhere on the board
PulseVS+: C33.1, R20.2; also elsewhere on the board

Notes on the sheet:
These turn on / off resistor values are on the higher (safer) side for Q3's gate capacitance and rated turn on / off times, and can modified after prototype evaluation
10:1 Attenuator
V_{ADJ} = (V_{DDB} - GND_DRV) * (R_{ADJ1}/R_{ADJ1}+R_{ADJ2}) UVLO = 5V = 2 * (1 + R_{ADJ1}/R_{ADJ2}) R_{ADJ1} = 20k R_{ADJ2} = (5/2 - 1) * 20k = 30k
20:1 Attenuator
Place C27, 29, 30 Near VSSB Place C28 across VDDB and VSSB

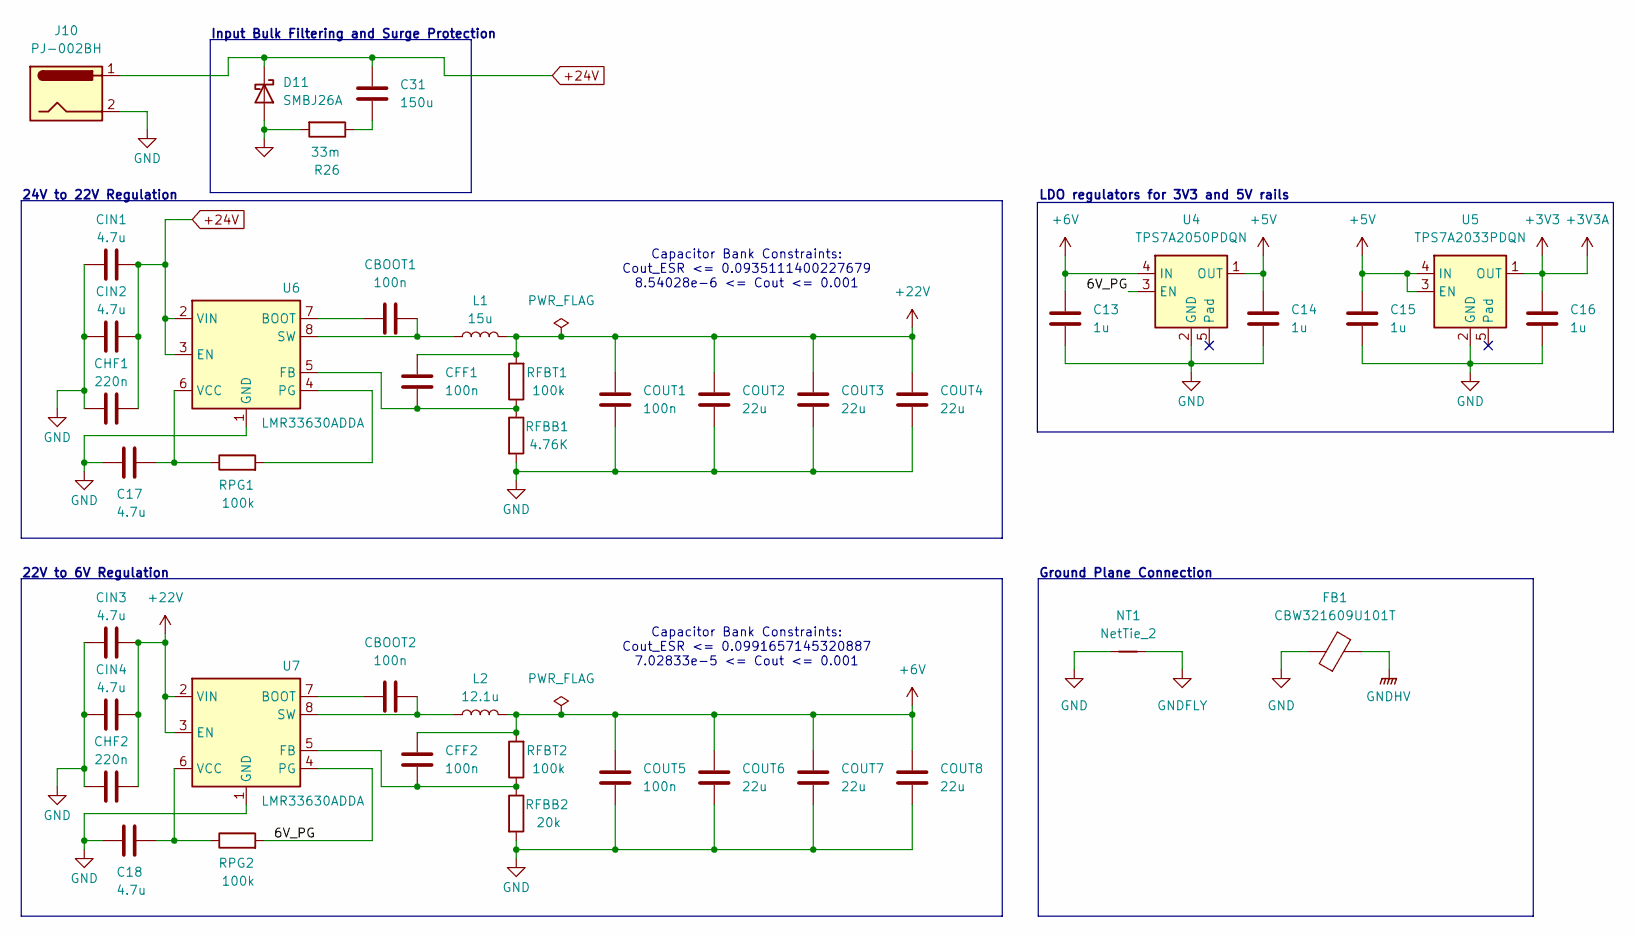
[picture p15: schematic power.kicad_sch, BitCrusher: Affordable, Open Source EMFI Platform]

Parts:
C13, C14, C15, C16: 1u; C_0402_1005Metric
C17, C18: 4.7u; C_1206_3216Metric
C31: 150u; C_Radial_D10.0mm_H20.0mm_P5.00mm
CBOOT1, CBOOT2: 100n; C_0402_1005Metric
CFF1, CFF2: 100n; C_0402_1005Metric
CHF1, CHF2: 220n; C_0805_2012Metric
CIN1, CIN2, CIN3, CIN4: 4.7u; C_1206_3216Metric
COUT1, COUT5: 100n; C_0402_1005Metric
COUT2, COUT3, COUT4, COUT6, COUT7, COUT8: 22u; C_1210_3225Metric
D11: SMBJ26A; D_SMB
FB1: CBW321609U101T; L_1206_3216Metric
J10: PJ-002BH; PJ-002B_CUI
L1: 15u; L_TechFuse_SL0630
L2: 12.1u; L_TechFuse_SL0630
NT1: NetTie_2; NetTie-2_SMD_Pad2.0mm
R26: 33m; R_0603_1608Metric
RFBB1: 4.76K; R_0603_1608Metric
RFBB2: 20k; R_0603_1608Metric
RFBT1, RFBT2: 100k; R_0603_1608Metric
RPG1, RPG2: 100k; R_0603_1608Metric
U4: TPS7A2050PDQN; Texas_X2SON-4_1x1mm_P0.65mm
U5: TPS7A2033PDQN; Texas_X2SON-4_1x1mm_P0.65mm
U6, U7: LMR33630ADDA; Texas_HSOP-8-1EP_3.9x4.9mm_P1.27mm_ThermalVias

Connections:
+3V3: C16.1, U5.1 (OUT); also elsewhere on the board
+5V: C14.1, C15.1, U4.1 (OUT), U5.3 (EN), U5.4 (IN); also elsewhere on the board
+6V: C13.1, CFF2.2, COUT5.2, COUT6.2, COUT7.2, COUT8.2, L2.2, RFBT2.2, U4.4 (IN); also elsewhere on the board
+22V: CFF1.2, CHF2.1, CIN3.1, CIN4.1, COUT1.2, COUT2.2, COUT3.2, COUT4.2, L1.2, RFBT1.2, U7.2 (VIN), U7.3 (EN); also elsewhere on the board
+24V: C31.1, CHF1.1, CIN1.1, CIN2.1, D11.1 (K), J10.1, U6.2 (VIN), U6.3 (EN)
/Primary Power Distribution/6V_PG: RPG2.2, U4.3 (EN), U7.4 (PG)
GND: C13.2, C14.2, C15.2, C16.2, C17.2, C18.2, CHF1.2, CHF2.2, CIN1.2, CIN2.2, CIN3.2, CIN4.2, COUT1.1, COUT2.1, COUT3.1, COUT4.1, COUT5.1, COUT6.1, COUT7.1, COUT8.1, D11.2 (A), FB1.1, J10.2, NT1.1, R26.2, RFBB1.2, RFBB2.2, U4.2 (GND), U5.2 (GND), U6.1 (GND), U6.9 (GND), U7.1 (GND), U7.9 (GND); also elsewhere on the board
GNDFLY: NT1.2; also elsewhere on the board
unnamed: C31.2, R26.1
unnamed: CBOOT1.1, U6.7 (BOOT)
unnamed: CFF1.1, RFBB1.1, RFBT1.1, U6.5 (FB)
unnamed: RPG1.2, U6.4 (PG)
unnamed: CBOOT1.2, L1.1, U6.8 (SW)
unnamed: C17.1, RPG1.1, U6.6 (VCC)
unnamed: CBOOT2.1, U7.7 (BOOT)
unnamed: CFF2.1, RFBB2.1, RFBT2.1, U7.5 (FB)
unnamed: CBOOT2.2, L2.1, U7.8 (SW)
unnamed: C18.1, RPG2.1, U7.6 (VCC)
PulseCS-: FB1.2; also elsewhere on the board

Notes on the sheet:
24V to 22V Regulation
Capacitor Bank Constraints: Cout_ESR <= 0.0991657145320887 7.02833e-5 <= Cout <= 0.001
LDO regulators for 3V3 and 5V rails
Capacitor Bank Constraints: Cout_ESR <= 0.0935111400227679 8.54028e-6 <= Cout <= 0.001
Ground Plane Connection
Input Bulk Filtering and Surge Protection
22V to 6V Regulation

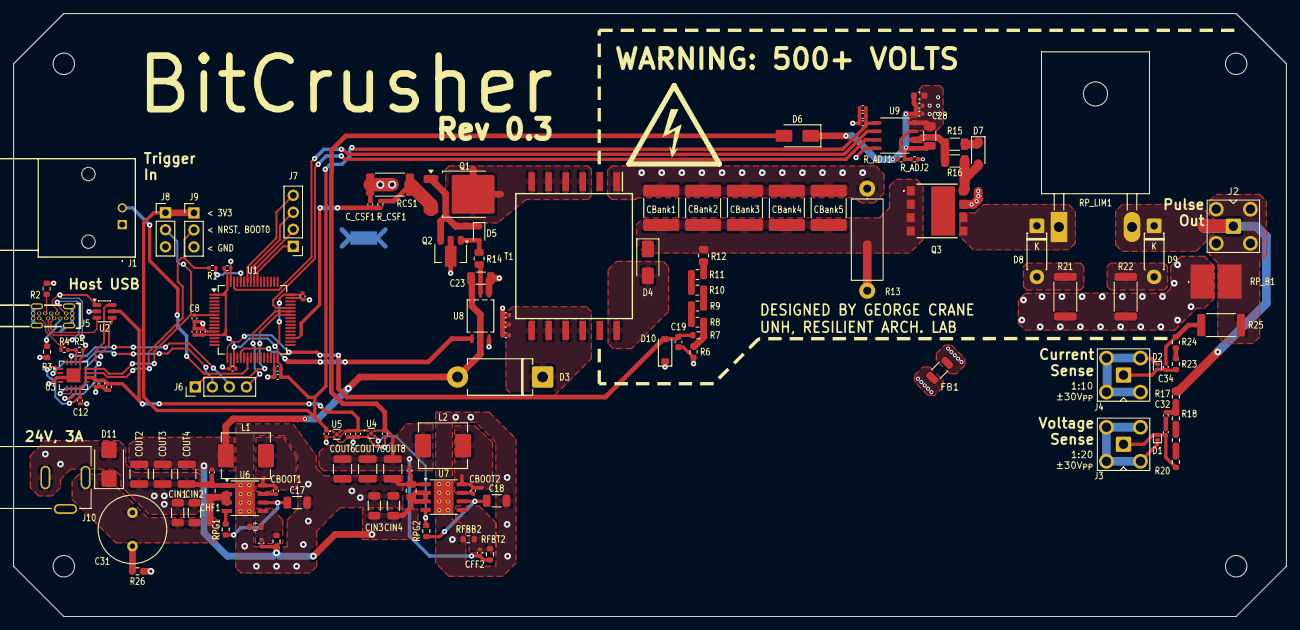
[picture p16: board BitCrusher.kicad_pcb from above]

Board: 2 copper layers, 190.0 x 90.0 mm, 138 parts (1 on the bottom side), 77 nets.

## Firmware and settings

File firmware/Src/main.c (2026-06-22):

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
/* Includes ------------------------------------------------------------------*/
#include "main.h"
// #include "interfaces_conf.h"
// #include "app_openbootloader.h"
#include "adc.h"
#include "comp.h"
#include "dac.h"
#include "flyback_control.h"
#include "stm32f303xe.h"
#include "stm32f3xx_hal.h"
#include "stm32f3xx_hal_adc.h"
#include "stm32f3xx_hal_comp.h"
#include "stm32f3xx_hal_dac.h"
#include "stm32f3xx_hal_dac_ex.h"
#include "stm32f3xx_hal_def.h"
#include "stm32f3xx_hal_gpio.h"
#include "stm32f3xx_hal_tim.h"
#include "stm32f3xx_hal_uart.h"
#include "tim.h"
#include "usart.h"
#include "gpio.h"
#include "protocol.h"
#include "arming.h"
#include <stddef.h>
#include <stdint.h>
#include <stdio.h>
#include <string.h>
// #include <sys/_pthreadtypes.h>

/* USER CODE BEGIN PM */
#define FLAG_ARMED (uint8_t )0xff
#define FLAG_DISARMED (uint8_t )0x00
#define STATE_INIT (uint8_t )0x01

// #define PULSE_EN_ALWAYS
/* USER CODE END PM */


/* USER CODE BEGIN PV */
// UART msg buffers
uint8_t uart_buf[MSG_MAX_LEN];
msg_hdr_t msg_hdr;
msg_len_t msg_len;
uint8_t msg_body[BODY_MAX_LEN];

// armed flag (set and checked when the device is in an armed state)
uint8_t armed = 0;

// device state variable
uint8_t dev_state = STATE_INIT;

// flyback PI control config and handle
PI_handle_t flyback_PWM_PI_hdl = {0.0, 0.0, 0.0, 0.0};


arming_config_t arming_config = {
  0,
  1,
  0,
  0
};

/* USER CODE END PV */

void SystemClock_Config(void);
/* USER CODE BEGIN 0 */

// Get message from UART, decode into msg_hdr, msg_len, and msg_body vars
// Also checks header validity
// returns HAL error code from receiving UART message
HAL_StatusTypeDef get_message(void) {
  // get hdr byte and len byte, validate 
  uint8_t hdr_and_len[2];
  HAL_StatusTypeDef res = HAL_UART_Receive(&huart1, hdr_and_len, 2, 1000);

  if (res == HAL_TIMEOUT) return HAL_TIMEOUT;

  if (res != HAL_OK || !is_valid_header(hdr_and_len[0])) return HAL_ERROR;
  msg_hdr = hdr_and_len[0];
  msg_len = hdr_and_len[1];

  // get the message body
  if (msg_len > 0) {
    res = HAL_UART_Receive(&huart1, msg_body, (uint16_t )msg_len, 100);
    if (res != HAL_OK) return HAL_ERROR;
  }
  return HAL_OK;
}

// Encode message from msg_hdr, msg_len, and msg_body, and send over UART
// returns 1 on error, 0 on success
int send_message(void) {
  // validate header, format message
  if (!is_valid_header(msg_hdr)) return 1;
  uart_buf[0] = msg_hdr;
  uart_buf[1] = msg_len;
  memcpy((void *)uart_buf+2, (void *)msg_body, msg_len);

  // send over UART
  // TODO: error check
  HAL_StatusTypeDef res = HAL_UART_Transmit(&huart1, uart_buf, (uint16_t)msg_len+2, 100);
  msg_hdr = HDR_ERROR;
  msg_len = 0;
  if (res != HAL_OK) return 1;
  return 0;
}

// write length and value of arming param to msg buffer (or `HDR_ERROR` on failure). 
// The arming parameter to check and copy is selected by casting `msg_body[0]` to
// `uint8_t`. Returns 0 on success or 1 on failure. 
int get_arm_param(void) {
  if (msg_len != 1) return 1;

  // lock values
  uint8_t field = (uint8_t )msg_body[0];

  switch (field) {
    case 0: {
      msg_len = 2;
      msg_hdr = HDR_SUCCESS;
      memcpy((void *)msg_body, (void *)&arming_config.voltage, 2);
      return 0;
      break;
    }
    case 1: {
      msg_len = 1;
      msg_hdr = HDR_SUCCESS;
      memcpy((void *)msg_body, (void *)&arming_config.trigger_polarity, 1);
      return 0;
      break;
    }
    case 2: {
      msg_len = 1;
      msg_hdr = HDR_SUCCESS;
      memcpy((void *)msg_body, (void *)&arming_config.trigger_mode, 1);
      return 0;
      break;
    }
    case 3: {
      msg_len = 1;
      msg_hdr = HDR_SUCCESS;
      memcpy((void *)msg_body, (void *)&arming_config.trigger_src, 1);
      return 0;
      break;
    }
    default: {
      msg_len = 0;
      msg_hdr = HDR_ERROR;
      return 1;
      break;
      // TODO: Write a utility func or macro to do error / success responses
      // TODO: Also, decide if the error response should come from here
      // or the calling function checking the error code of this call...
    }
  }
}

// validate field and value in msg body and apply the value to the given field.
// if field validation fails, returns 1. If successful, returns 0.
int set_arm_param(void) {
  // msg_body: [uint8 field, uint{8, 16} val]
  if (msg_len < 2) return 1;

  // lock values
  uint8_t field = (uint8_t )msg_body[0];
  void *val_ptr = (void *)msg_body+1;

  switch (field) {
    case 0: {
      uint16_t val = *(uint16_t *)val_ptr;
      if (val < 150 || val > 500) {
        return 1;
      }
      arming_config.voltage = val;
      return 0;
      break;
    }
    case 1: {
      uint8_t val = *(uint8_t *)val_ptr;
      if (val != 0 && val != 1) {
        return 1;
      }
      arming_config.trigger_polarity = val;
      return 0;
      break;
    }
    case 2: {
      uint8_t val = *(uint8_t *)val_ptr;
      if (val != 0 && val != 1) {
        return 1;
      }
      arming_config.trigger_mode = val;
      return 0;
      break;
    }
    case 3: {
      uint8_t val = *(uint8_t *)val_ptr;
      if (val != 0 && val != 1) {
        return 1;
      }
      arming_config.trigger_src = val;
      return 0;
      break;
    }
    default: {
      msg_len = 0;
      msg_hdr = HDR_ERROR;
      return 1;
      break;
      // TODO: decide if the error response should come from here
      // or the calling function checking the error code of this call...
    }
  }
}

// check arming config and arm device. Return 1 on error or 0 on success
int arm_device(void) {
  // validate arming config, return error response if invalid
  if (!is_valid_arming_config(&arming_config)) return 1;
  // if device is already armed, return success here
  if (armed == FLAG_ARMED) return 0;

  // set the "PulseEN" GPIO (gate driver EN pin is low active)
  HAL_GPIO_WritePin(GPIOA, PulseEN_Pin, GPIO_PIN_RESET);

  // change the trigger comparator output back from being GPIO forced low
  // HAL_GPIO_DeInit(PulseEN_GPIO_Port, PulseEN_Pin);
  // MX_COMP2_Init();

  // reset the `TIM3` WDT counter value and make sure it's not stopped (it's on one-pulse mode)
  // htim3.Instance->EGR &= TIM_EGR_UG;  // generate update event, clearing CNT
  // htim3.Instance->CR1 &= TIM_CR1_CEN;  // enable counting
  HAL_COMP_Start(&hcomp3);
  HAL_COMP_Start(&hcomp2);
  HAL_GPIO_WritePin(GPIOD, GPIO_PIN_2, GPIO_PIN_RESET);
  HAL_TIM_OnePulse_Start(&htim3, TIM_CHANNEL_1);
  // tim3 output goes high here

  HAL_ADC_Start(&hadc1);
  
  // set flyback PSR Ilim (DAC)
  HAL_DAC_SetValue(&hdac1, DAC_CHANNEL_1, DAC_ALIGN_12B_R, (uint32_t )V_to_DAC(V_ILIM));
  HAL_DAC_Start(&hdac1, DAC_CHANNEL_1);
  
  // start HVPWM
  HAL_TIM_PWM_Start(&htim2, TIM_CHANNEL_1);
  HAL_TIM_PWM_Start(&htim2, TIM_CHANNEL_4);
  
  // set armed flag
  armed = FLAG_ARMED;  // device is now armed
  return 0; 
}

int disarm_device(void) {
  // reset PulseEN GPIO pin
  HAL_GPIO_WritePin(GPIOA, PulseEN_Pin, GPIO_PIN_SET);
  
  // disable trigger comparator
  // HAL_COMP_DeInit(&hcomptrig);
#ifndef PULSE_EN_ALWAYS
  HAL_COMP_Stop(&hcomp2);
#endif
  HAL_COMP_Stop(&hcomp3);

  MX_GPIO_Init();  // (this also resets PulseEN_Pin)

  // nothing needs to happen with TIM3 since it generates no interrupts and is in
  // one pulse mode

  // disable PWM output
  htim2.Instance->CCR1 = 0;
  HAL_TIM_PWM_Stop(&htim2, TIM_CHANNEL_1);
  HAL_TIM_PWM_Stop(&htim2, TIM_CHANNEL_4);

  HAL_DAC_Stop(&hdac1, DAC_CHANNEL_1);

  // htim2.Instance->CR1 &= ~TIM_CR1_CEN;  // disable counting
  HAL_ADC_Stop(&hadc1);

  // reset armed flag
  armed = FLAG_DISARMED;
  return 0;
}

int flyback_comp_step(void) {
  // Convert ADC reading to float in [0, 500]
  HAL_StatusTypeDef res = HAL_ADC_PollForConversion(&hadc1, 10);
  if (res != HAL_OK) return 1;
  uint32_t adc_reading = HAL_ADC_GetValue(&hadc1) & 0x0fff;
  float V_HV_fb = ADC_TO_V(adc_reading);  // voltage measured at HVVS
  float HV_fb = V_TO_VHV(V_HV_fb);  // real voltage at HV bank
  float setpoint = (float )arming_config.voltage;

  // Run PI on normalized input
  PI_step(&flyback_PWM_PI_cfg, &flyback_PWM_PI_hdl, HV_fb/HV_MAX, setpoint/HV_MAX);
  // flyback_PWM_PI_hdl.out *= 1;
  flyback_PWM_PI_hdl.out *= (1 + RAMP(setpoint));
  float CS_ctrl = flyback_PWM_PI_hdl.out;

  memcpy(msg_body, &V_HV_fb, sizeof(float));  // wrtie ADC reading to UART
  memcpy(msg_body+sizeof(float), &HV_fb, sizeof(float));  // wrtie ADC reading to UART
  memcpy(msg_body+(2*sizeof(float)), &flyback_PWM_PI_hdl.err, sizeof(float));  // wrtie ADC reading to UART
  msg_len = 3*sizeof(float);
  
  // Force control signal inbounds
  if (flyback_PWM_PI_hdl.out < 0){
    flyback_PWM_PI_hdl.out = 0;
    // CS_ctrl = 0.0;
  } else if (flyback_PWM_PI_hdl.out < D_MIN) {
    // prevent shorter pulses than gate driver is rated for
    __HAL_TIM_SET_AUTORELOAD(&htim2, PWM_P*6);
    flyback_PWM_PI_hdl.out = D_MIN;
    // CS_ctrl = 0.0;
  } else {
    __HAL_TIM_SET_AUTORELOAD(&htim2, PWM_P);
    // If the bank isn't even close to the setpoint yet, just run at max duty cycle
    if (flyback_PWM_PI_hdl.err > HV_COMP_WINDOW || flyback_PWM_PI_hdl.out > D_MAX) {
      flyback_PWM_PI_hdl.out = D_MAX;
      CS_ctrl = 1.0;
    }
  }

  // update PWM duty cycle
  uint32_t duty_cycle = (uint32_t )(flyback_PWM_PI_hdl.out * PWM_P);
  htim2.Instance->CCR1 = duty_cycle;

  // update primary current limit
  HAL_DAC_SetValue(&hdac1, DAC_CHANNEL_1, DAC_ALIGN_12B_R, (uint32_t )V_to_DAC(D_TO_ILIM(CS_ctrl)));


  return 0;
}

int armed_loop(void) {
  if (armed != FLAG_ARMED) {
    disarm_device();
    return 1;
  }

  // check for fault conditions
  // check if the handshake timer period has expired
  if (HAL_GPIO_ReadPin(GPIOA, GPIO_PIN_6) != GPIO_PIN_SET) {
    // period expired, check for host handshake msg
    if (get_message() != HAL_OK) {
      return 1;
    }

    if (msg_hdr != HDR_ARM) {
      // If msg has DISARM header, disarm immedietly and return success
      if (msg_hdr == HDR_DISARM) {
        if (disarm_device()) return 1;
        return 0;
      }

      // If header is something else, return error
      return 1;
    }

    // if received valid handshake, reset timer and remain armed
    HAL_GPIO_WritePin(GPIOD, GPIO_PIN_2, GPIO_PIN_SET);
    HAL_GPIO_WritePin(GPIOD, GPIO_PIN_2, GPIO_PIN_RESET);
  } else {
    // period not expired, remain armed
  }
  
  // if the program reaches here, the device should still be armed.
  // run the compensation loop (just once per armed_loop call i guess)
  // and adjust the flyback converter PWM
  if (flyback_comp_step()) {
    // disarm_device();
    return 1;
  }

  return 0;
}

// For now, error responses propagate up to here, where they are handled
int process_command(void) {
  // Each valid message header has a function to process it
  switch (msg_hdr) {

    case HDR_GET_STATE: {
      return 1;
      break;
    }

    case HDR_GET_ARM_PARAM: {
      if (get_arm_param()) {
        msg_hdr = HDR_ERROR;
        msg_len = 0;
        return 1;
      } else {
        // get_arm_param already filled the message buffers
        // with the correct info, so it just needs to get sent
        return 0;
      }
      break;
    }

    case HDR_SET_ARM_PARAM: {
      if (set_arm_param()) {
        msg_hdr = HDR_ERROR;
        msg_len = 0;
        return 1;
      } else {
        msg_hdr = HDR_SUCCESS;
        msg_len = 0;
        return 0;
      }
      break;
    }

    case HDR_ARM: {
      if (arm_device()) {
        disarm_device();
        msg_hdr = HDR_ERROR;
        msg_len = 0;
        return 1;
      }
      // tell host the device armed successfully
      msg_hdr = HDR_SUCCESS;
      msg_len = 0;
      send_message();

      // start host handshake loop
      int res = 0;
      while (!res && armed == FLAG_ARMED) {
        // armed_loop returns 0 when disarmed intentionally, which could allow this to keep running maybe
        res = armed_loop();
        if (res) {
          disarm_device();
          msg_hdr = HDR_ERROR;
          msg_len = 0;
          return 1;
        } else {
          msg_hdr = HDR_SUCCESS;
          // msg_len = 0; // msg buffer holds current feedback value
          send_message();
        }
      }
      
      if (armed != FLAG_DISARMED) {
        disarm_device();
        msg_hdr = HDR_ERROR;
        msg_len = 0;
        return 1;
      } else {
        msg_hdr = HDR_SUCCESS;
        msg_len = 0;
        return 0;
      }

      break;
    }

    case HDR_DISARM: {
      // Disarming from an armed state is handled from within processing
      // the `arm` command.
      msg_hdr = HDR_ERROR;
      msg_len = 0;
      return 1;
    }
  }

  msg_hdr = HDR_ERROR;
  msg_len = 0;
  return 1;
}


/* USER CODE END 0 */

/**
  * @brief  The application entry point.
  * @retval int
  */
int main(void)
{
  /* Reset of all peripherals, Initializes the Flash interface and the Systick. */
  HAL_Init();

  /* USER CODE BEGIN Init */

  /* Configure the system clock */
  SystemClock_Config();

  /* USER CODE BEGIN SysInit */

  /* Initialize all configured peripherals */
  MX_GPIO_Init();
  MX_ADC1_Init();
  MX_COMP2_Init();
  MX_COMP3_Init();
  MX_TIM2_Init();
  MX_DAC1_Init();
  MX_USART1_UART_Init();
  MX_TIM3_Init();

  // Basic command loop
  while (1) {
    int res;
    HAL_StatusTypeDef msg_res = get_message();
    if (msg_res == HAL_OK) {
      res = process_command();
      send_message();
    } else if (msg_res == HAL_TIMEOUT) {
      // timed out waiting for message, so carry on
    } else {
      // There was an error and an error response is in
      // the message buffer, so send it
      send_message();
    }

    // HAL_Delay(100);
  }
}



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


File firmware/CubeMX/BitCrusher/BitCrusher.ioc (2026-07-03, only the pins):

Mcu.UserName=STM32F303RETx
PA0.GPIO_Label=HVSense+
PA0.Signal=ADC1_IN1
PA1.GPIO_Label=HVSense-
PA1.Signal=ADC1_IN2
PA10.Signal=USART1_RX
PA11.GPIO_Label=PulseEN
PA11.Signal=GPIO_Output
PA2.Signal=OPAMP1_VOUT
PA3.Signal=OPAMP1_VINP
PA4.Signal=COMP_DAC11_group
PA5.GPIO_Label=HVPWM
PA5.Signal=S_TIM2_CH1_ETR
PA6.Signal=S_TIM3_CH1
PA7.GPIO_Label=HWTrig+
PA7.Signal=COMP2_INP
PA9.Signal=USART1_TX
PB14.GPIO_Label=HVCS
PB14.Signal=COMP3_INP
PB9.GPIO_Label=IntTrig+
PB9.Signal=COMP2_OUT
PD2.Signal=S_TIM3_ETR

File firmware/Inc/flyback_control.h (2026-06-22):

#ifndef __FLYBACK_CONTROL_H__
#define __FLYBACK_CONTROL_H__

#include <stdint.h>
#ifdef __cplusplus
extern "C" {
#endif

#include "main.h"

// voltage feedback conversion macros
// #define HVVS_MAX 3
#define HVVS_MAX 1.5
#define HVVS_MIN 0
#define VDDA (float )3.3
#define HV_MIN 150
#define HV_MAX 500
#define HV_COMP_WINDOW 0.1
#define RAMP(setpoint) 0 * (setpoint / HV_MAX)

// PWM duty cycle macros
#define D_MIN 0.08
#define D_MAX 0.29
#define PWM_P 720

// current limit trip level
#define V_ILIM_MAX 0.5
#define V_ILIM_MIN 0.2
#define V_ILIM V_ILIM_MAX
#define D_TO_ILIM(D) ((V_ILIM_MIN - V_ILIM_MAX)*D) + V_ILIM_MIN

// DEBUGGING:
//  1. get live readings from cap bank and measurement port, and compare
//  to sensed ADC voltage to make sure it matches.
//  2. simulate some results here with the expected range and make sure
//  the scaling is right and nothing is getting truncated 
constexpr uint16_t adc_meas_min = 0;
constexpr uint16_t adc_meas_max = 0x0fff;
#define ADC_TO_V(x) ((x * 3.3f) / (float) adc_meas_max)
#define VHV_OFFSET 0.85
#define V_TO_VHV(x) ((float )HV_MAX/(float )(HVVS_MAX - HVVS_MIN))*(x - VHV_OFFSET)
constexpr uint16_t adc_meas_test = adc_meas_max-3000;
constexpr float adc_to_v_test = ADC_TO_V(adc_meas_test);
constexpr float v_to_vhv_test = V_TO_VHV(adc_meas_test);

typedef struct {
    float Kp;       // proportional gain
    float Ki;       // integral gain
    float T;        // timestep for integral / derivative calculation
} PI_config_t;

// persistent state / cache of the PID controller instance
typedef struct {
    float it;           // integral result
    float dv;           // derivative result
    float err;          // error value
    float out;          // output value
    // float out_norm;     // normalized output
} PI_handle_t;

constexpr PI_config_t flyback_PWM_PI_cfg = {
    1.0,
    0.0,
    1.0
};

void PI_step(const PI_config_t *cfg, PI_handle_t *pi, float fb, float set);

#ifdef __cplusplus
}
#endif
#endif /*__ FLYBACK_CONTROL_H__ */

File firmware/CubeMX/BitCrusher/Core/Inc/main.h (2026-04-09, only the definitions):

#define TIM2_PWM_Period 100000
#define HVSense__Pin GPIO_PIN_0
#define HVSense__GPIO_Port GPIOA
#define HVSense_A1_Pin GPIO_PIN_1
#define HVSense_A1_GPIO_Port GPIOA
#define HVPWM_Pin GPIO_PIN_5
#define HVPWM_GPIO_Port GPIOA
#define HWTrig__Pin GPIO_PIN_7
#define HWTrig__GPIO_Port GPIOA
#define HVCS_Pin GPIO_PIN_14
#define HVCS_GPIO_Port GPIOB
#define PulseEN_Pin GPIO_PIN_11
#define PulseEN_GPIO_Port GPIOA
#define IntTrig__Pin GPIO_PIN_9
#define IntTrig__GPIO_Port GPIOB

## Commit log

2025-11-08 added kicad project
    [BitCrusher.kicad_pcb, BitCrusher.kicad_sch, control.kicad_sch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]
2025-11-09 started microcontroller setup
    [control.kicad_sch]
2025-11-10 started primary power distribution design
    [BitCrusher.kicad_sch, control.kicad_sch, hv-bank.kicad_sch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]
2025-11-12 hv generation planning
    [hv-gen.kicad_sch]
2025-11-26 added CubeMX files, worked on microcontroller schematic
    [BitCrusher.kicad_sch, control.kicad_sch, hv-gen.kicad_sch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]
2025-11-28 figuring out triggering scheme
    [control.kicad_sch]
2025-12-01 started USB-C interface design
    [BitCrusher.kicad_sch, control.kicad_sch, hv-switch.kicad_sch]
2025-12-05 Working on GaNFET driver circuit for HV switching
    [BitCrusher.kicad_sch, hv-switch.kicad_sch]
2025-12-07 Working on high voltage switching
    [BitCrusher.kicad_sch, control.kicad_sch, hv-gen.kicad_sch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]
2025-12-20 assembling final components for HV switching
    [control.kicad_sch, hv-switch.kicad_sch]
2025-12-21 Continuing work on HV switching and primary power distribution
    [hv-gen.kicad_sch, hv-switch.kicad_sch, power.kicad_sch]
2025-12-26 Finished flyback voltage sense divider
    [hv-gen.kicad_sch]
2025-12-27 Working on probe voltage and current sense circuits
    [control.kicad_sch, hv-gen.kicad_sch, hv-switch.kicad_sch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]
2025-12-30 Trying to figure out high side driver level shifting
    [hv-switch.kicad_sch]
2025-12-31 Fixed gate drive UVLO
    [control.kicad_sch, hv-switch.kicad_sch]
2026-01-04 Added low pass filter to high voltage sensing circuit
    [hv-gen.kicad_sch]
2026-01-08 Switched to FT230X UART bridge
    [control.kicad_sch]
2026-01-12 Finished new UART bridge circuit
    [control.kicad_sch]
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2026-01-13 Primary power buck regulator
    [control.kicad_sch, hv-gen.kicad_sch, power.kicad_sch]
2026-01-13 Almost finished primary power regulation
    [hv-switch.kicad_sch, power.kicad_sch]
2026-01-14 working on measurement buffers
    [control.kicad_sch, hv-switch.kicad_sch]
2026-01-17 Working on measure buffers and assigning footprints
    [control.kicad_sch, hv-gen.kicad_sch, hv-switch.kicad_sch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]
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2026-01-25 Added resistor networks
    [hv-switch.kicad_sch, resistor-networks.kicad_sch]
2026-01-26 more footprint assignment
    [hv-gen.kicad_sch, hv-switch.kicad_sch]
2026-01-26 Footprint assignment / part selection
    [control.kicad_sch, hv-gen.kicad_sch, hv-switch.kicad_sch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]
2026-01-26 More footprint assignment and component selection
    [control.kicad_sch, hv-gen.kicad_sch, hv-switch.kicad_sch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]
2026-01-28 More footprint assignment (almost done)
    [control.kicad_sch, hv-gen.kicad_sch, hv-switch.kicad_sch]
2026-01-28 Done with component selection / footprint assignment
    [control.kicad_sch, hv-gen.kicad_sch, hv-switch.kicad_sch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]
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2026-01-29 Starting PCB layout
    [BitCrusher.kicad_pcb, control.kicad_sch, hv-gen.kicad_sch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]
2026-01-29 Layout Work
    [BitCrusher.kicad_pcb]
2026-01-30 Primary power layout
    [BitCrusher.kicad_pcb, power.kicad_sch]
2026-02-02 More layout work
    [BitCrusher.kicad_pcb, control.kicad_sch]
2026-02-04 Working on layout
    [BitCrusher.kicad_pcb, control.kicad_sch, hv-gen.kicad_sch]
2026-02-06 Swapped resistor networks for shunt resistors
    [BitCrusher.kicad_pcb, resistor-networks.kicad_sch]
2026-02-08 Fixing DRC stuff
    [BitCrusher.kicad_pcb, hv-gen.kicad_sch]
2026-02-09 Fixed (almost) all DRC errors
    [BitCrusher.kicad_pcb, hv-gen.kicad_sch]
2026-02-09 Almost done with layout
    [BitCrusher.kicad_pcb, BitCrusher.kicad_sch, control.kicad_sch]
2026-02-11 Fixing layout and parts selection issues for prototype run
    [BitCrusher.kicad_pcb, hv-switch.kicad_sch, power.kicad_sch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]
2026-02-11 added working BOM
    [bom-JLCPCB BitCrusher.xls]
2026-02-11 More little fixes
    [BitCrusher.kicad_pcb, hv-gen.kicad_sch, hv-switch.kicad_sch]
2026-02-11 Switched to larger via's for big cost saving
    [BitCrusher.kicad_pcb]
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2026-02-22 starting 3D modeling of case
    [BitCrusher.step, Unnamed.FCStd]
2026-02-22 Added missing 3d models
    [ANT-TH_KH-BNC50-3511.step, BitCrusher.kicad_pcb, BitCrusher.step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]
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2026-02-24 fixed message handling bugs
    [main.c]
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2026-03-01 Increased trace width from flyback shunt resistor to ground
    [BitCrusher.kicad_pcb]
2026-03-02 fixed component value typo
    [hv-gen.kicad_sch]
2026-03-03 trying and failing to figure out open bootloader
    [main.c]
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2026-03-04 switched to correct bootloader UART pins
    [BitCrusher.ioc]
2026-03-06 Fixed PNP turnoff circuit, increased measurement buffer spacing
    [BitCrusher.kicad_pcb, hv-gen.kicad_sch]
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2026-03-07 moved in old flyback converter simulation
    [flyback-test.kicad_pcb, flyback-test.kicad_sch]
2026-03-08 moved in old flyback sim
    [flyback-test.kicad_pcb, flyback-test.kicad_sch]
2026-03-08 more flyback sim work
    [flyback-test.kicad_pcb, flyback-test.kicad_sch]
2026-03-09 corrected Q1 footprint and orientation
    [BitCrusher.kicad_pcb, hv-gen.kicad_sch]
2026-03-10 flyback voltage sense filter testing
    [flyback-vs-sim.kicad_pcb, flyback-vs-sim.kicad_sch]
2026-03-10 Reduced HVVS filter capacitance
    [hv-gen.kicad_sch]
2026-03-11 no sim errors now
    [flyback-test.kicad_sch]
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2026-03-14 Figuring out HV switching issue
    [BitCrusher.kicad_pcb, hv-switch.kicad_sch]
2026-03-15 tweaked high voltage fet driver circuit and layout
    [BitCrusher.kicad_pcb, hv-switch.kicad_sch]
2026-03-15 Modified high voltage gate drive circuit and layout, added net tie from GND to flyback converter GND
    [BitCrusher.kicad_pcb, hv-gen.kicad_sch, hv-switch.kicad_sch]
2026-03-18 Altered HVCS filter, replaced some high current traces with filled zones, added labels
    [BitCrusher.kicad_pcb, control.kicad_sch, hv-gen.kicad_sch]
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2026-03-24 added ferrite bead between HVGND and GND
    [BitCrusher.kicad_pcb, BitCrusher.kicad_sch, control.kicad_sch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]
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2026-04-08 Fixed BNC footprint polarity
    [BitCrusher.kicad_pcb]
2026-04-09 fixed internal trigger pin setting
    [BitCrusher.ioc, main.h]
2026-04-15 async arming bug fix
    [device.py]
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2026-04-23 moved high voltage switching component selection from old repo
    [FET-products.ods]
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2026-07-05 more diode failure
2026-07-06 Power supply hot plug simulation
    [power-filtering.kicad_pcb, power-filtering.kicad_sch]
2026-07-06 Improved power supply filtering and surge protection
    [BitCrusher.kicad_pcb, control.kicad_sch, hv-gen.kicad_sch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]
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2026-07-19 Changed TVS diodes on measurement bufferes to match 0-25V expected range.
    [BitCrusher.kicad_pcb, control.kicad_sch]
2026-07-19 updated measurement buffer docs
    [BitCrusher.kicad_pcb]
2026-07-29 Reduced usage of 0.2mm traces (which don't fab well)
    [BitCrusher.kicad_pcb]
2026-08-18 Replace HV bootstrap diode with properly spec'd fast recovery diode
    [BitCrusher.kicad_pcb, hv-switch.kicad_sch]
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

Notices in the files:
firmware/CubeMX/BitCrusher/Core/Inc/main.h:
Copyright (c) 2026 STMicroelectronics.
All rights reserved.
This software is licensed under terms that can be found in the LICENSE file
